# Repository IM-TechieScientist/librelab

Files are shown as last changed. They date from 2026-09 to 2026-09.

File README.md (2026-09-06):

# LibreLab

LibreLab is a low-cost, open lab instrument for embedded developers: part logic analyser, part mixed-signal scope, part signal generator, part protocol workbench. The goal is simple: make the kind of debug workflow people buy premium USB instruments for available as open hardware and open software at student/hacker-lab pricing.

Current hardware is targeting a PCB+BOM cost below `₹2500`, roughly `$26.4` at recent INR/USD rates. The next hardware revision is targeting a sub-`$50` build with RP2350B, an AD9629-class high-speed ADC path, HSTX-based high-speed data movement toward a USB 3-class host link, and generous PSRAM buffering.

## Hardware Preview

<table>
  <tr>
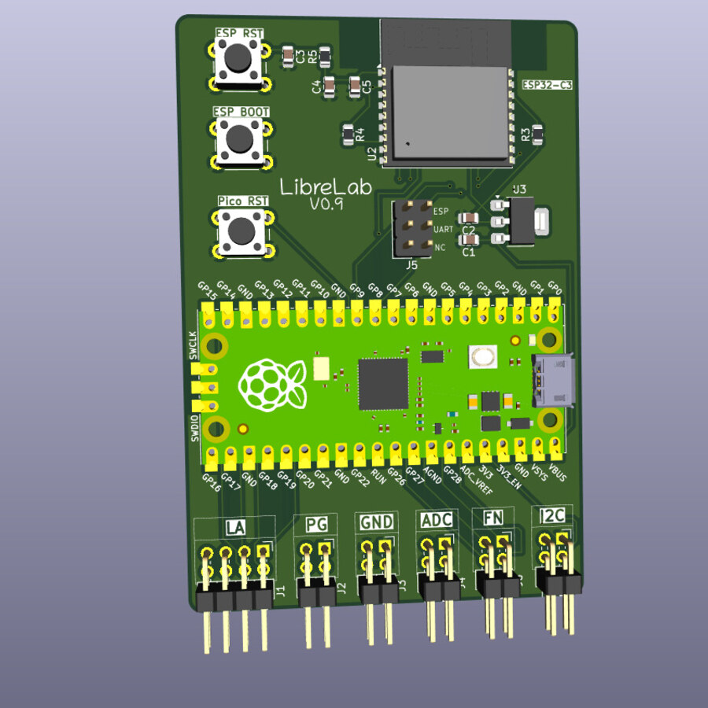
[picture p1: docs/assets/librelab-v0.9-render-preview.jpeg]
LibreLab v0.9 assembled board render
    <td width="33%"></td>
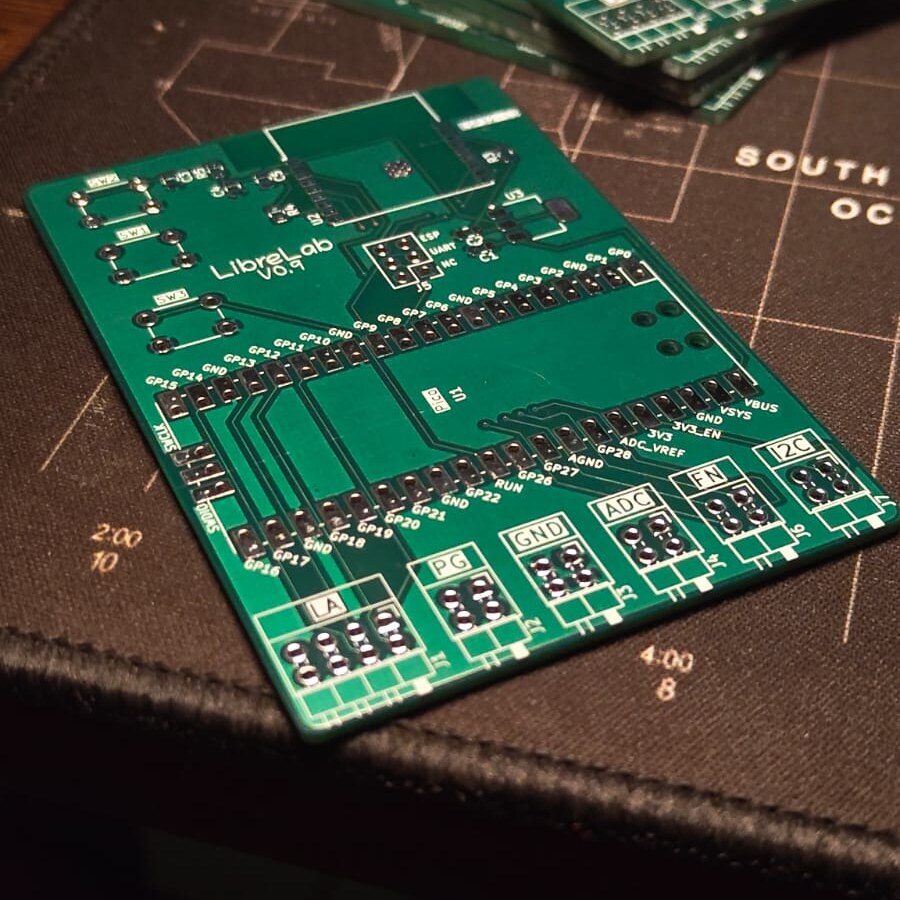
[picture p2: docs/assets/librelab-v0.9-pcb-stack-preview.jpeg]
LibreLab v0.9 PCB panel photo
    <td width="33%"></td>
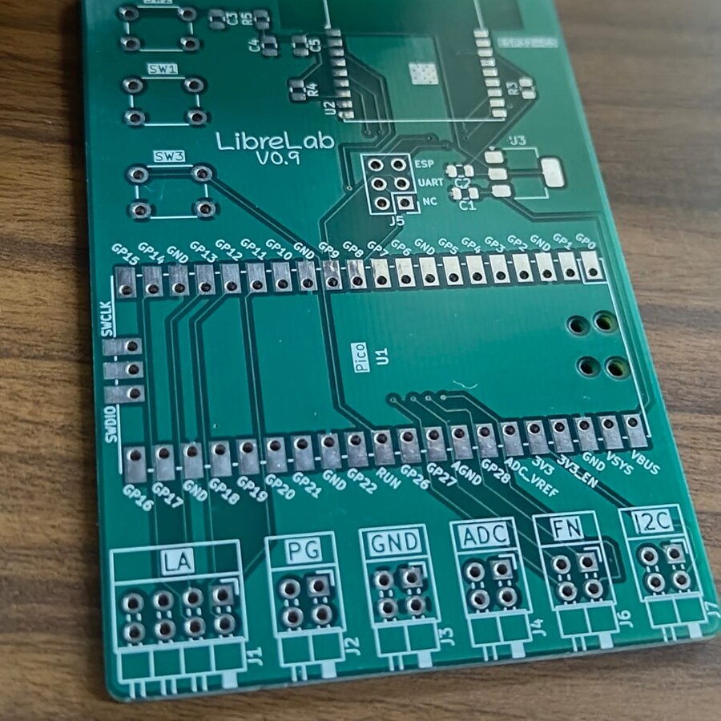
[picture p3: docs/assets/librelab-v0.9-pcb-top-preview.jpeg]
LibreLab v0.9 PCB top photo
    <td width="33%"></td>
  </tr>
  <tr>
    <td align="center">v0.9 board render</td>
    <td align="center">fabricated PCB stack</td>
    <td align="center">PCB top side</td>
  </tr>
</table>

## Software Preview

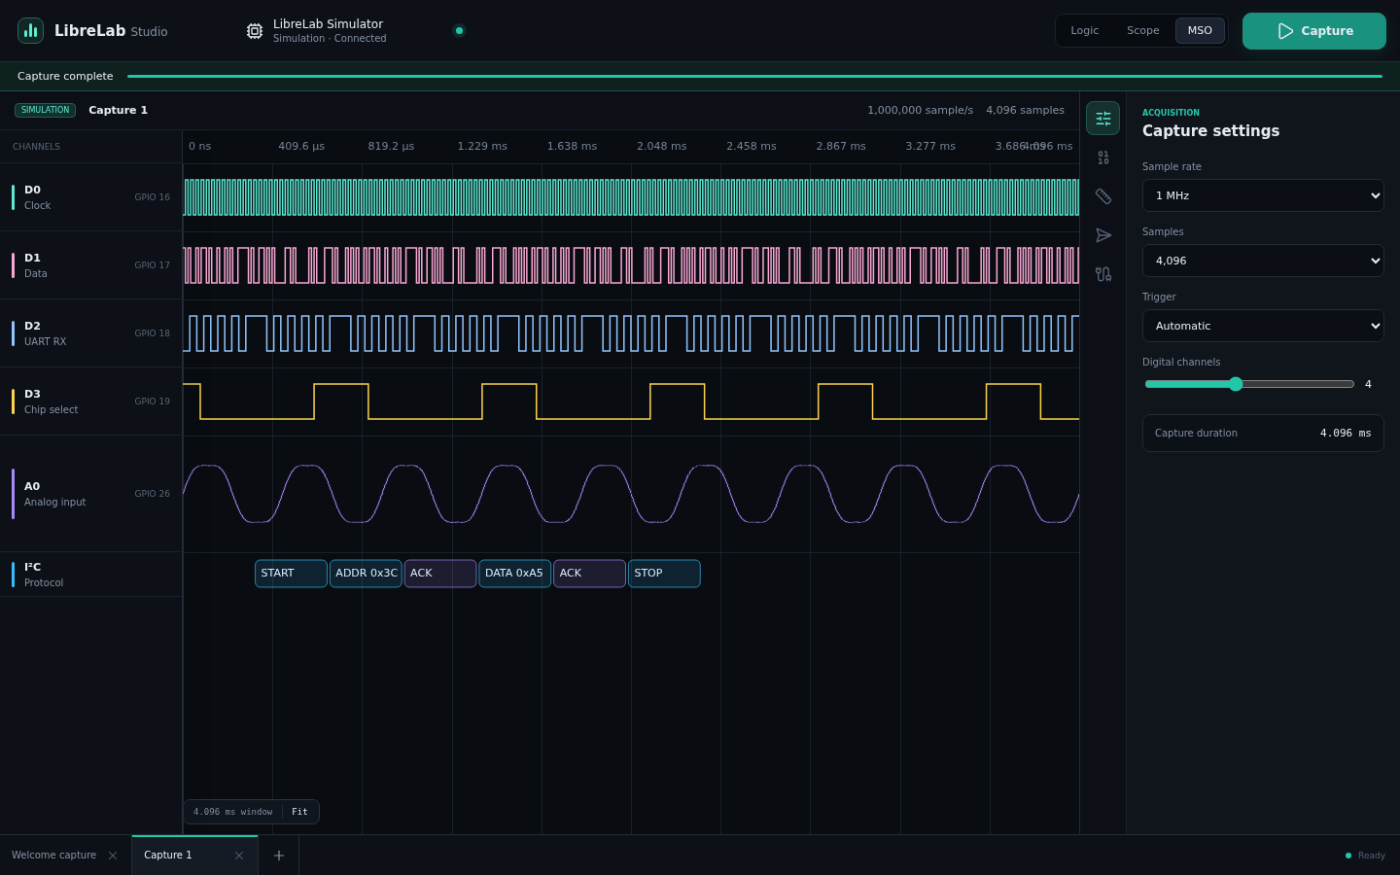
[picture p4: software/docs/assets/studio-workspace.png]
LibreLab Studio capture workspace


## Why This Is Interesting

Saleae's current Logic 8 is an 8-channel USB analyser rated at up to 100 MS/s digital capture, 10 MS/s analog capture, 10-bit analog resolution, long PC-streamed captures, 25+ protocol decoders, trigger/search, measurements, automation, and cross-platform software.

LibreLab is aiming at that workflow from the other side of the cost curve:

- `150 MSPS` logic capture on the current RP2350 design path.
- `200 MSPS` logic capture under active development.
- `400 MSPS` burst-mode capture under active development.
- Logic analyser, oscilloscope, mixed-signal capture, pattern generation, test outputs, and bus gateways in one firmware stack.
- USB CDC SCPI today, with optional ESP32-C3 Wi-Fi bridge transport.
- First-party modern desktop software plus PulseView/libsigrok integration for people who prefer the classic sigrok workflow.
- Roadmap hardware aimed at high-speed analog capture and deeper buffering while staying below `$50`.

The bet is that a carefully designed RP2350-class instrument can be brutally useful for firmware bring-up, protocol debugging, education, and small-lab automation without needing a $500-class box on every desk.

## Current Firmware

The firmware lives in [firmware](firmware/) and currently targets Pico 2/RP2350A. Firmware was originally developed by me as part of GSoC 2026.

Implemented so far:

- SCPI 1999-style command interface over USB CDC.
- 1-8 channel PIO/DMA logic analyser.
- One-channel RP2350 internal-ADC oscilloscope path.
- Synchronized mixed-signal one-shot capture.
- 1-8 channel digital pattern generator.
- UART and I2C bus gateways.
- SPI gateway code path, with a known bus-number mismatch still to fix.
- Square-wave and PWM-based analog test outputs.
- ESP32-C3 bridge firmware for TCP SCPI, UDP capture frames, SoftAP provisioning, and mDNS.
- Out-of-tree libsigrok/PulseView driver source.

Useful docs:

- [Firmware README](firmware/README.md)
- [Firmware architecture](firmware/docs/architecture.md)
- [SCPI command reference](firmware/docs/scpi-reference.md)
- [Hardware resources](firmware/docs/hardware.md)
- [RP2350B migration plan](firmware/docs/rp2350b-migration.md)

## Current Software

The desktop application lives in [software](software/) and is built with Electron, React, and TypeScript.

Implemented so far:

- Saleae-style capture workspace with channel rail, session tabs, timeline canvas, and right-side inspector.
- Logic, scope, and mixed-signal modes.
- Deterministic simulator device, so the GUI can be tested without hardware.
- Digital and analog waveform rendering with zoom, pan, fit, hover cursor, and A/B markers.
- Analyzer, measurement, output, and bus-console panels.
- Simulated I2C annotation lane using the same annotation model planned for libsigrokdecode.
- Unit, component, build, and GUI smoke tests.

More:

- [Software README](software/README.md)
- [Software architecture](software/docs/architecture.md)
- [Software feature map](software/docs/features.md)
- [Software testing](software/docs/testing.md)

Run it:

```bash
cd software
npm install
npm run dev
```

Run the browser-rendered GUI for quick UI work:

```bash
cd software
npm run dev:renderer -- --host 127.0.0.1
```

## Hardware Snapshot

The KiCad project lives in [pcb/librelab](pcb/librelab/). The current schematic/PCB includes:

- Raspberry Pi Pico module footprint.
- ESP32-C3-WROOM-02 wireless bridge module.
- AMS1117-3.3 regulator.
- Logic analyser headers.
- Pattern-generator headers.
- ADC headers.
- I2C headers.
- Function/test-output headers.
- Ground headers and reset/boot buttons.
- Generated fabrication outputs under `pcb/librelab/output/`.

## Roadmap

Near-term:

- Connect LibreLab Studio to the real USB SCPI firmware.
- Add capture import/export formats.
- Wire libsigrokdecode into a worker so GUI protocol annotations come from real decoders.
- Finish the SPI gateway bus-number fix.
- Keep PulseView support working alongside the first-party app.

Hardware vNext:

- RP2350B for a cleaner, conflict-free pin map.
- AD9629-class external ADC frontend for serious analog capture.
- HSTX-based high-speed data path toward USB 3-class streaming.
- PSRAM-backed captures and burst buffering.
- 200 MSPS sustained logic capture target and 400 MSPS burst experiments.
- Sub-`$50` target cost.

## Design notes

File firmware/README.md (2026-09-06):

# LibreLab Pico firmware

Firmware for the RP2350-based LibreLab Pico instrument, plus companion firmware
for an ESP32-C3 Wi-Fi bridge. The current build targets Pico 2/RP2350A; a future
LibreLab PCB is planned around the 48-GPIO RP2350B. The RP2350 exposes a SCPI
interface over USB CDC and implements digital capture, analog capture,
mixed-signal acquisition, pattern generation, peripheral-bus gateways, test
outputs, and optional wireless transport.

Features and limits below describe the current build.

## What is included

| Area | Capability | Current state |
| --- | --- | --- |
| Control | SCPI 1999 command parser over USB CDC | Built and usable |
| Logic analyser | 1–8 consecutive GPIO channels, PIO/DMA capture, triggers, finite capture, streaming | Built and usable |
| Oscilloscope | One RP2350 ADC channel, DMA capture, level/edge trigger, finite capture, streaming | Built and usable |
| Mixed-signal | Synchronized digital and analog one-shot capture | Built and usable |
| Pattern generator | 1–8 consecutive GPIO outputs, packed patterns, one-shot/loop modes | Built and usable |
| Bus gateway | UART1 and I2C0/I2C1 access through SCPI | Built; observe pin conflicts |
| Bus gateway | SPI1 access through SCPI | Compiled, but blocked by a known logical bus-number mismatch |
| Test outputs | Digital square wave and PWM-based “analog” waveform | Built and usable |
| Wireless | ESP32-C3 SPI bridge, TCP SCPI, UDP captures, SoftAP provisioning, mDNS | Built and usable with two-board wiring |
| ADC abstraction | ADC frontend registry with RP2350 internal ADC backend | Built and used by DSO/MSO |
| Host integration | Out-of-tree libsigrok/PulseView driver | Source included; integration into libsigrok is manual |

## Quick start

### Requirements

- Raspberry Pi Pico SDK 2.1 or newer
- CMake 3.13 or newer
- Ninja or Make
- Arm GNU toolchain (`arm-none-eabi-gcc`)
- A Pico 2/RP2350A board for the current target

Set `PICO_SDK_PATH` to the SDK checkout, then configure and build:

```bash
export PICO_SDK_PATH=/path/to/pico-sdk
cmake -S . -B build-pico2 -DPICO_BOARD=pico2
cmake --build build-pico2 --target librelab_pico -j
```

The useful outputs are normally:

```text
build-pico2/librelab_pico.elf
build-pico2/librelab_pico.bin
build-pico2/librelab_pico.hex
build-pico2/librelab_pico.uf2
```

Hold BOOTSEL while connecting the Pico, then copy the UF2 file to the mounted
`RPI-RP2` volume. Alternatively, use a debug probe or `picotool`.

After reboot, find the CDC port and query the device:

```bash
python3 -m serial.tools.miniterm /dev/ttyACM0 115200 --raw
```

Then send:

```text
*IDN?
```

Expected identification:

```text
FOSSASIA,LibreLab Pico,1.0,v0.1.0
```

The baud value is conventional for terminal software; USB CDC does not use it
to clock the physical USB connection.

## Feature examples

SCPI keywords are case-insensitive. Uppercase letters in the reference indicate
the required short form; lowercase letters are optional. Terminate commands
with `\n` or `\r\n`.

Logic analyser one-shot capture:

```text
LA:CONF:PINB 16
LA:CONF:PINC 2
LA:CONF:SAMP 1024
LA:CONF:TRIG:MODE AUTO
LA:READ?
```

Oscilloscope capture on ADC0/GPIO26:

```text
DSO:CONF:CHAN 0
DSO:CONF:RATE 100000
DSO:CONF:SAMP 1024
DSO:CONF:TRIG:MODE OFF
DSO:READ?
```

I2C two-byte read:

```text
BUS:I2C:CONF:BUS 1
BUS:I2C:CONF:ADDR 60
BUS:I2C:OPEN
BUS:I2C:READ? 2
```

Binary arguments and responses use SCPI definite-length arbitrary blocks. See
[SCPI command reference](docs/scpi-reference.md) and
[binary data formats](docs/data-formats.md) before writing a host client.

## Hardware resources at a glance

This is the current Pico 2/RP2350A mapping, not the planned RP2350B mapping.

| Function | Default RP2350 resources |
| --- | --- |
| Logging | UART0 TX GPIO0, RX GPIO1, 115200 8N1 |
| Wi-Fi bridge | SPI0 GPIO2–5, READY GPIO6 |
| UART gateway | UART1 TX GPIO4, RX GPIO5 |
| I2C gateway | I2C0 GPIO0/1 or I2C1 GPIO6/7 |
| SPI gateway | SPI1 SCK GPIO10, MOSI GPIO11, MISO GPIO12, CS GPIO13 |
| Square test output | GPIO15, 1 kHz, 50% duty |
| PWM “analog” test output | GPIO13, 1 kHz, 50% duty |
| Logic analyser | GPIO16 onward; 2 channels by default |
| Pattern generator | GPIO16 onward; 1 channel by default |
| Mixed-signal digital | GPIO16 onward; 1 channel by default |
| Internal ADC | ADC0–ADC3 on GPIO26–GPIO29 |

These defaults overlap. In particular, UART1 overlaps the Wi-Fi bridge, I2C0
overlaps the logging UART, I2C1 overlaps the Wi-Fi READY pin, GPIO13 is shared by
the default SPI chip-select and PWM test output, and the default LA/MSO/pattern
generator all begin at GPIO16. There is no central pin-ownership manager yet.
Read [hardware resources](docs/hardware.md) before enabling features together.

RP2350B provides 48 rather than 30 GPIOs, so a new PCB can assign all of these
functions to different pads. That makes the present pad conflicts avoidable,
but it is not a drop-in firmware change: RP2350B analog inputs are GPIO40–47,
PIO access to GPIO32–47 uses the GPIO16–47 window, and this source currently
contains A-specific pin limits and mappings. See the verified
[RP2350B PCB and firmware migration plan](docs/rp2350b-migration.md).

## Documentation

- [Documentation index](docs/README.md)
- [Getting started](docs/getting-started.md)
- [Building and flashing](docs/building.md)
- [Hardware resources and wiring](docs/hardware.md)
- [RP2350B PCB and firmware migration](docs/rp2350b-migration.md)
- [Firmware architecture](docs/architecture.md)
- [Complete SCPI command reference](docs/scpi-reference.md)
- [Binary and transport data formats](docs/data-formats.md)
- [Testing](docs/testing.md)
- [Development guide](docs/development.md)
- [Troubleshooting](docs/troubleshooting.md)

Feature guides:

- [Logic analyser](docs/features/logic-analyser.md)
- [Oscilloscope](docs/features/oscilloscope.md)
- [Mixed-signal capture](docs/features/mixed-signal.md)
- [Digital pattern generator](docs/features/pattern-generator.md)
- [UART, I2C, and SPI gateways](docs/features/bus-gateways.md)
- [Test-signal outputs](docs/features/test-signals.md)
- [Wi-Fi bridge](docs/features/wifi-bridge.md)
- [Internal ADC frontend](docs/features/adc-frontends.md)

## Repository layout

```text
src/application/        SCPI parser integration and feature command adapters
src/system/             Hardware-independent instruments, buses, transport, logging setup
src/platform/           RP2350/Pico SDK drivers
src/util/               Circular buffer, error, and logging utilities
esp_firmware/           ESP-IDF project for the ESP32-C3 bridge
tools/sigrok/           Out-of-tree libsigrok driver
lib/                    Vendored firmware dependencies
docs/                   User, protocol, architecture, and developer documentation
```

The runtime starts in `src/application/main.c`, initializes system services,
initializes the SCPI protocol, then repeatedly services USB, Wi-Fi command
polling, instrument streams, the pattern generator, and buffered logs.

## Known limitations

- The SPI SCPI gateway uses external bus number `1`, while its system layer
  currently exposes one logical bus numbered `0`; `BUS:SPI:OPEN` therefore
  fails until those conventions are aligned.
- Non-automatic finite LA triggers and triggered finite DSO captures can wait
  indefinitely if the trigger never arrives. MSO uses a one-second timeout;
  streaming DSO uses a 10 ms trigger timeout per frame.
- LA and DSO streaming are mutually exclusive. MSO has no streaming mode.
- The 1024-byte SCPI input buffer limits the effective size of a single
  `PG:DATA` upload even though the pattern buffer itself is 64 KiB.
- Wi-Fi command polling is disabled in the default USB transport mode. Select
  `COMM:TRAN WIFI` or `COMM:TRAN AUTO` over USB before controlling a newly
  booted Pico only through Wi-Fi.

## License

LibreLab firmware sources are licensed under Apache-2.0. Vendored components
retain their own licenses; see [LICENSE.md](LICENSE.md) and the license files in
`lib/`.

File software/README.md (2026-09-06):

# LibreLab Studio

LibreLab Studio is the desktop control and analysis application for LibreLab instruments. The current implementation is an Electron, React, and TypeScript app with a Saleae-style capture workspace, a deterministic simulator, and automated tests that run without hardware.

This is the first vertical slice. It is designed so the UI, capture contract, renderer tests, and GUI smoke tests are usable now while the native hardware engine and libsigrokdecode bridge are added behind the same API.

## What Works Today

- Logic, oscilloscope, and mixed-signal workspace modes.
- Built-in LibreLab simulator exposed through the same API shape planned for hardware devices.
- Capture settings for sample rate, sample count, trigger mode, and digital channel count.
- Timeline viewport with digital traces, analog traces, zoom, pan, fit, hover cursor, and A/B marker measurement.
- I2C-style protocol annotations in the simulator.
- Analyzer, measurement, output, and bus-console side panels.
- Browser-side fallback simulator for component tests.
- GUI smoke test that captures data without hardware.

## Screenshots

LibreLab Studio capture workspace

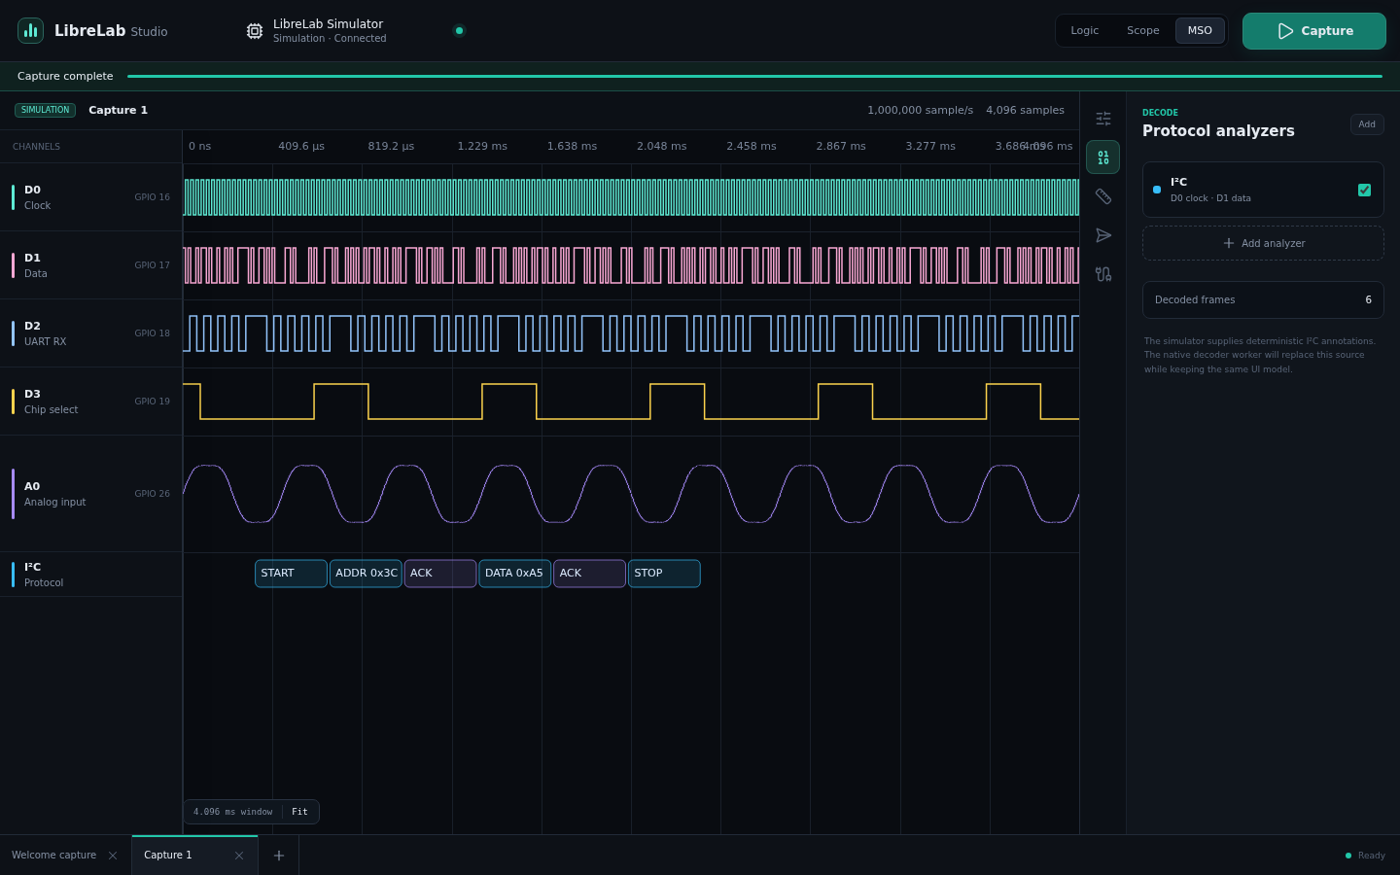
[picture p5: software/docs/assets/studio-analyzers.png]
LibreLab Studio analyzer panel


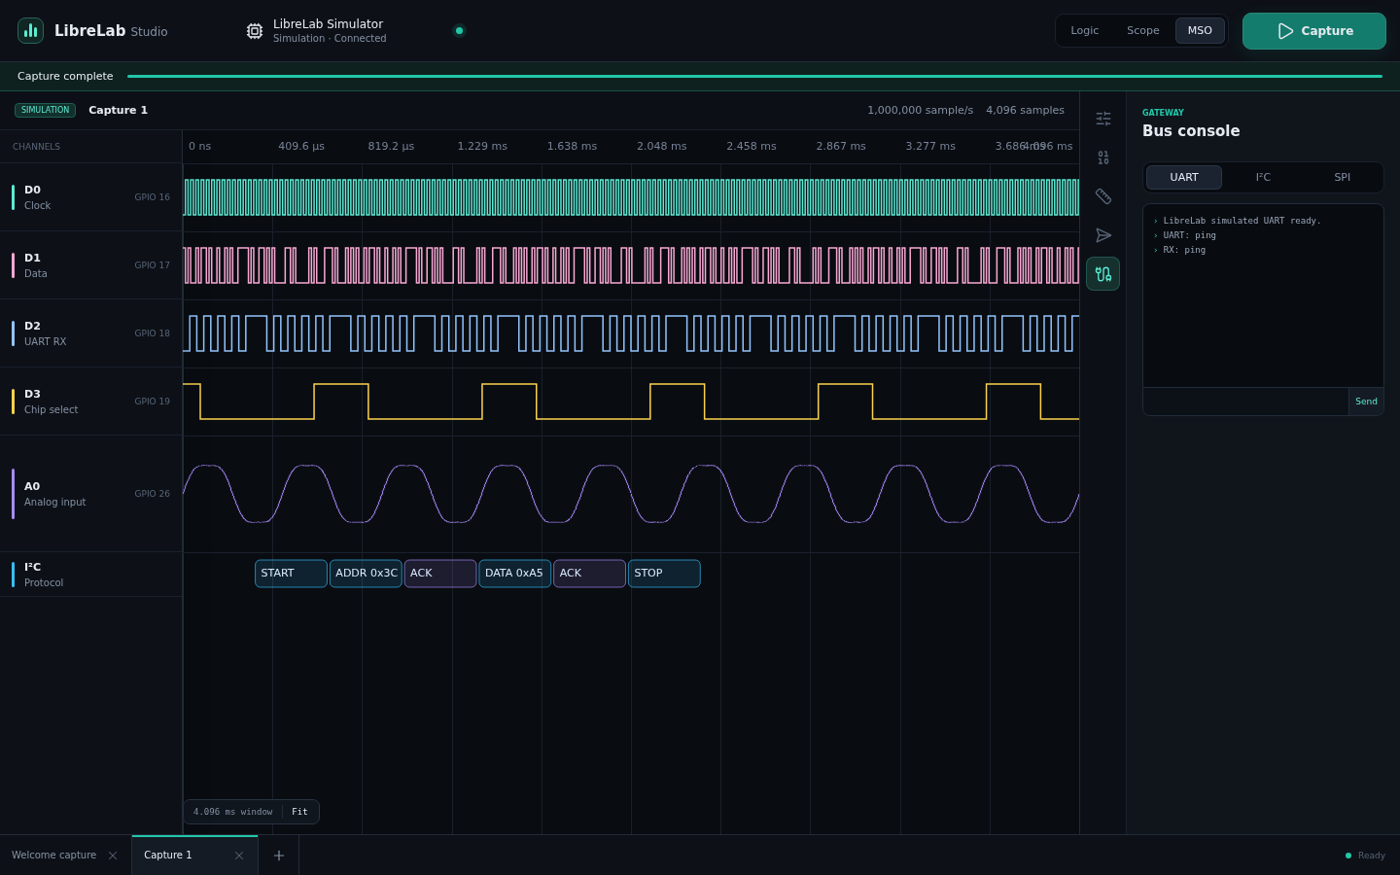
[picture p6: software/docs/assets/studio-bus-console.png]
LibreLab Studio bus console


## Commands

Run from this directory:

```bash
npm install
npm run dev
npm run typecheck
npm test
npm run test:e2e
npm run test:all
npm run docs:screenshots
npm run build
npm run package
```

`npm run dev` starts the Electron development app.

`npm run dev:renderer` starts only the renderer in a browser. This is useful for fast UI work and is the mode used by Playwright smoke tests.

`npm test` runs unit and component tests in jsdom.

`npm run test:e2e` builds the desktop app and runs the Playwright GUI smoke test against the renderer simulator in Chromium. On a fresh machine, install the Playwright browser once:

```bash
npx playwright install chromium
```

`npm run docs:screenshots` refreshes the screenshots in `docs/assets/`.

## Project Layout

```text
software/
  src/main/              Electron main process and device-service IPC
  src/preload/           Secure context bridge exposed as window.librelab
  src/renderer/src/      React app, waveform canvas, panels, styles
  src/shared/            Capture/device contracts and deterministic simulator
  tests/e2e/             Playwright GUI smoke tests
  docs/                  Architecture and testing notes
```

## Development Notes

The renderer never talks directly to Node, USB, or native libraries. It calls `window.librelab`, which is provided by the preload script in Electron and by a browser simulator in tests. That keeps the app secure and makes every GUI workflow testable without plugging in a board.

The future hardware path should implement the existing shared contracts first, then replace the mock device service with a native device engine. Protocol decoding should follow the same pattern: the UI consumes annotation records; a native worker can later fill those records from libsigrokdecode.

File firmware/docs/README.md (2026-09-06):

# LibreLab firmware documentation

This directory is the authoritative documentation for the integrated RP2350
firmware and ESP32-C3 bridge. Unless a section is explicitly marked as a future
RP2350B design, values and limitations describe the current Pico 2/RP2350A
source tree.

## Start here

1. [Getting started](getting-started.md) — build, flash, connect, and run a first capture.
2. [Hardware resources](hardware.md) — pin mapping, wiring, voltage rules, and conflicts.
3. [RP2350B migration](rp2350b-migration.md) — verified package differences,
   conflict-free routing example, and required firmware work.
4. [SCPI command reference](scpi-reference.md) — every command registered by the firmware.
5. [Binary data formats](data-formats.md) — arbitrary blocks, packed samples, USB streams, and Wi-Fi frames.

## Build and maintenance

- [Building and flashing](building.md) — RP2350 and ESP32-C3 toolchains and artifacts.
- [Testing](testing.md) — build verification, sigrok tests, and current test-suite status.
- [Development guide](development.md) — source ownership, adding features, style, and review checklist.
- [Troubleshooting](troubleshooting.md) — common build, USB, capture, bus, and wireless failures.

## Architecture

- [Firmware architecture](architecture.md) — layer boundaries, boot flow,
  runtime scheduling, errors, and resource ownership.
- [RP2350B migration](rp2350b-migration.md) — future PCB pin planning and
  package-aware architecture changes.
- [Binary data formats](data-formats.md) — application and bridge protocol layouts.
- [Wi-Fi bridge](features/wifi-bridge.md) — two-MCU architecture, provisioning, TCP, UDP, SPI, and mDNS.

## Feature guides

| Feature | Guide |
| --- | --- |
| PIO/DMA logic analyser | [Logic analyser](features/logic-analyser.md) |
| Internal-ADC oscilloscope | [Oscilloscope](features/oscilloscope.md) |
| Synchronized analog + digital capture | [Mixed-signal capture](features/mixed-signal.md) |
| PIO/DMA digital output | [Pattern generator](features/pattern-generator.md) |
| UART, I2C, and SPI host gateways | [Bus gateways](features/bus-gateways.md) |
| Digital and PWM test outputs | [Test signals](features/test-signals.md) |
| USB/TCP/UDP wireless transport | [Wi-Fi bridge](features/wifi-bridge.md) |
| Internal ADC abstraction | [ADC frontend](features/adc-frontends.md) |

## Documentation conventions

- GPIO numbers are RP2350 GPIO numbers, not physical header pin numbers.
- Rates are in hertz unless explicitly labelled otherwise.
- Timeouts exposed by SCPI are in milliseconds; lower layers commonly store
  them in microseconds.
- `uint16_t` and `uint32_t` payloads are little-endian.
- In SCPI command spellings, uppercase characters form the legal short form and
  lowercase characters are optional.
- “Built” means the file is listed in the root `CMakeLists.txt`; it does not
  imply that every combination of features is electrically conflict-free.

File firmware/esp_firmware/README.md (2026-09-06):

# LibreLab ESP32-C3 bridge firmware

This ESP-IDF project is the optional network companion for LibreLab Pico. It is
an SPI slave to the RP2350 and provides SoftAP provisioning, station-mode Wi-Fi,
TCP SCPI on port 5006, UDP captures on port 5005, UDP receiver registration,
and mDNS as `librelab-pico.local` / `_librelab._tcp`.

Build and flash from an ESP-IDF 5.1.x shell:

```bash
idf.py set-target esp32c3
idf.py menuconfig
idf.py build
idf.py -p /dev/ttyUSB0 flash monitor
```

Default ESP pins are GPIO4 SCLK, GPIO5 MOSI, GPIO6 MISO, GPIO7 CS, and GPIO10
READY. Default provisioning uses AP `LibreLab-Pico-XXXX`, password
`librelab-pico`, and setup page `http://192.168.4.1`.

Read the complete [Wi-Fi bridge guide](../docs/features/wifi-bridge.md),
[wire protocol](../docs/data-formats.md), and
[troubleshooting guide](../docs/troubleshooting.md). `bridge_receiver.py` is a
synthetic-pattern link diagnostic, not a decoder for current capture payloads.

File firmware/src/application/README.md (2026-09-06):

# Application layer

This directory owns the RP2350 firmware's SCPI-facing application layer:

- `main.c` initializes the system and protocol, then runs the cooperative loop.
- `protocol/common.c` owns the parser context, complete command table, USB/Wi-Fi
  response routing, stream dispatch, and SCPI reset callback.
- `protocol/{la,dso,mso,pg}.c` and `protocol/bus/` parse parameters and format
  results.
- `*_commands.c` files retain feature configuration and adapt commands to the
  system layer.
- `gateway/` adapts the UART, I2C, and SPI SCPI gateways.

The SCPI input buffer is 1,024 bytes and the error queue contains 16 entries.
The current identification response is:

```text
FOSSASIA,LibreLab Pico,1.0,v0.1.0
```

See the authoritative [architecture](../../docs/architecture.md), complete
[SCPI reference](../../docs/scpi-reference.md), and
[development guide](../../docs/development.md).

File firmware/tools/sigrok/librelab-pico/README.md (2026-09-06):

# LibreLab Pico libsigrok Driver

This directory is an out-of-tree `libsigrok` hardware driver for the LibreLab
Mini/Pico firmware. It talks to the firmware over USB CDC using the existing
SCPI commands and feeds unpacked `SR_DF_LOGIC` samples to PulseView.

## Firmware Requirements

Flash firmware that includes:

- `LA:CONFigure:TRIGger:MODE AUTO`
- `LA:CONFigure:RATE?`
- `LA:METadata?`
- `LA:READ?` returning a SCPI arbitrary block of little-endian packed
  `uint32_t` PIO/DMA words

`AUTO` trigger mode is important because PulseView captures usually start
without a hardware trigger.

## Build Into libsigrok

1. Copy this directory to `libsigrok/src/hardware/librelab-pico`.
2. Add the directory to libsigrok's hardware-driver build files.
3. Add `librelab_pico_driver_info` to the libsigrok hardware driver registry if
   your libsigrok checkout requires explicit registration.
4. Build and install libsigrok, then build PulseView against that libsigrok.

The driver is intentionally small and POSIX-serial based. Linux is the first
target; Windows/macOS can follow by replacing the serial transport in
`protocol.c` with libsigrok's serial helpers.

## Usage

```sh
sigrok-cli --driver librelab-pico:conn=/dev/ttyACM0 --samples 1024
```

PulseView should then show `librelab-pico` as a sigrok hardware driver. Select the
CDC device path as the connection, choose enabled channels, set sample count and
sample rate, capture, and use the normal PulseView protocol decoders.

## Capture Format

Firmware returns packed PIO/DMA words. The host unpacker uses:

```text
bits_per_word = 32 - (32 % pin_count)
```

Each sample consumes `pin_count` bits. The output byte maps bit 0 to `D0`, bit
1 to `D1`, and so on.

## Local Test

The unpacker can be tested without libsigrok:

```sh
make test
```

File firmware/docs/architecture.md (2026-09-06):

# Firmware architecture

## System overview

LibreLab is split across one required MCU and one optional bridge MCU:

```text
                         USB CDC
Host <------------------------------------------------> RP2350
  ^                                                       |
  | TCP SCPI + UDP captures                               | SPI0 + READY
  +------------------------ ESP32-C3 <--------------------+
```

The RP2350 owns instrument state, capture/generation hardware, SCPI parsing, and
binary formatting. The ESP32-C3 is a transport bridge; it does not interpret
instrument commands or samples.

The current platform implementation is specialized for Pico 2/RP2350A. The
future RP2350B PCB needs a package-aware board configuration and pin map; see
[RP2350B migration](rp2350b-migration.md).

## RP2350 layers

```text
Application
  SCPI command tree, parser callbacks, feature adapters
        |
System
  Instruments, bus handles, transport policy, initialization, logging/syscalls
        |
Platform
  Pico SDK, PIO, DMA, ADC, UART, I2C, SPI, PWM, TinyUSB, GPIO
        |
RP2350 hardware
```

### Application layer

`src/application/protocol/common.c` owns the SCPI context, command table, input
buffers, output routing, and stream dispatch. Feature protocol files parse SCPI
parameters and translate failures into SCPI errors. Command-adapter files retain
application state where appropriate and call the system layer.

### System layer

The system layer defines hardware-independent handles and instrument behavior:

- `system/logic_analyser.*` — packed digital capture model.
- `system/instrument/dso.*` — one-channel analog acquisition and triggering.
- `system/instrument/mixed_signal.*` — coordinated PIO + ADC capture.
- `system/pattern_generator.*` — output lifecycle and modes.
- `system/instrument/adc_frontend.*` — selectable ADC backend registry.
- `system/bus/*` — handle ownership for UART/I2C/SPI.
- `system/transport.*` — USB/Wi-Fi policy and wireless capture framing.
- `system/system.*` — startup, reset, logging UART, and exception handling.

### Platform layer

Only platform modules should call Pico SDK hardware APIs. They implement
TinyUSB CDC, PIO state machines, DMA setup, internal ADC capture, UART IRQs,
I2C/SPI controllers, the Pico-to-ESP link, PWM outputs, clocks, watchdog reset,
and the status LED.

### Utility layer

`src/util` contains the circular buffer, logging queue, SI-prefix constants,
and the CException-based error model.

## Startup sequence

```text
main
  -> SYSTEM_init
       -> LOG_init
       -> PLATFORM_init
            -> register internal ADC frontend
       -> initialize UART0 logging and newlib syscalls
       -> status LED
       -> test-signal state
       -> TinyUSB CDC
       -> transport defaults (USB)
  -> protocol_init
       -> SCPI parser/context and command table
  -> forever
       -> protocol_task
       -> drain buffered logs
```

`protocol_task()` is cooperative, not an RTOS task. It services the pattern
generator, TinyUSB, up to 64 bytes of USB input, up to 256 bytes of wireless
input, then advances LA and DSO streams.

## Command flow

```text
USB CDC bytes or ESP SPI SCPI frame
  -> SCPI_Input
  -> command callback
  -> application adapter
  -> system instrument/bus
  -> platform driver
  -> response callback
  -> originating USB or Wi-Fi path
```

The active response destination is selected per command source. USB remains the
default after a wireless command finishes.

## Capture flow

### Logic analyser

PIO0 SM0 samples consecutive GPIO bits. RX FIFO requests drive a DMA channel
into a packed `uint32_t` buffer. The application supports finite capture and a
double-buffered stream.

### Oscilloscope

The ADC frontend selects the internal backend. ADC FIFO requests drive DMA into
a `uint16_t` buffer. Trigger detection is performed with single ADC reads before
the DMA acquisition begins.

### Mixed-signal

The ADC and logical analyser are configured and armed first. The logic trigger
is awaited, then ADC and PIO capture are started in sequence. Reported start
offsets are currently zero placeholders rather than measured skew.

### Pattern generation

PIO0 SM1 shifts packed samples to consecutive GPIO pins. A data DMA channel
feeds the TX FIFO; loop mode uses a control DMA channel to restart the transfer.

## Transport architecture

USB responses and finite captures use normal SCPI text or arbitrary blocks.
USB streams add a textual frame header before each arbitrary block. Wireless
captures are wrapped in an inner LibreLab capture frame, then a fixed 512-byte
Pico/ESP bridge frame. See [binary data formats](data-formats.md).

Transport policy is:

- `USB`: no Pico polling of the ESP command path; capture streams use USB.
- `WIFI`: initialize/use the ESP path and route capture streams through it.
- `AUTO`: use Wi-Fi when READY is asserted, otherwise USB.

## Errors and logging

SCPI errors and firmware logs are separate:

- Parse/command failures enter a 16-entry SCPI error queue read with
  `SYST:ERR?`.
- Internal logs enter a circular buffer and are drained to stdout/stderr.
- Newlib stdout/stderr is routed through UART0 at 115200 baud.
- An uncaught CException logs a fatal message, flushes logs with a bounded
  timeout, and resets through the watchdog.

## State and reset behavior

`*RST` resets LA, DSO, MSO, and pattern-generator state. It does not erase ESP
NVS, alter build-time pin mapping, or reboot either MCU. Bus gateway handles are
not explicitly reset by the SCPI reset callback in the current implementation.

## Concurrency and ownership constraints

- The RP2350 main loop is cooperative; long blocking captures delay other SCPI
  and log processing.
- Finite triggered LA/DSO operations may wait indefinitely.
- LA and DSO streams explicitly stop one another.
- MSO shares both LA and ADC resources but does not coordinate with an already
  active stream; clients should stop streams first.
- GPIO ownership is implicit. See [hardware resources](hardware.md).
- DMA channels are claimed dynamically, so initialization can fail when the
  pool is exhausted.

## Package boundary

RP2350A and RP2350B share the firmware layers and peripheral-controller model,
but the package is an explicit platform concern. Board-specific code must own:

- valid GPIO count and fixed peripheral pin routes;
- ADC channel count and channel-to-GPIO mapping;
- the PIO GPIO window shared by state machines on each PIO instance;
- LED, flash, ESP-link, gateway, and test-output assignments.

Those values are currently distributed as constants in platform, system, and
application modules. Consolidating them into a board profile is a prerequisite
for maintaining both A and B targets without silently applying A mappings to B.

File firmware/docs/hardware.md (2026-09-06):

# Hardware resources and wiring

The current firmware target is a Raspberry Pi Pico 2, which uses the 30-GPIO
RP2350A package, and optionally an ESP32-C3. A future LibreLab PCB is planned
around RP2350B. GPIO numbers below are chip GPIO numbers. Consult the board
pinout or schematic for physical positions.

RP2350B has enough additional pads to remove the conflicts in the current map,
provided the PCB and firmware assign each function a distinct compatible pad.
It does not automatically resolve conflicts in the current binary. See the
[RP2350B migration plan](rp2350b-migration.md) for the verified differences and
a candidate conflict-free allocation.

## Electrical rules

- RP2350 GPIO is 3.3 V logic and is not 5 V tolerant.
- Connect grounds between LibreLab, an ESP bridge, probes, and target circuits.
- Keep analog input voltage within the board/ADC limits.
- External I2C pull-ups must go to 3.3 V. The current default configuration also
  enables the RP2350 internal pull-ups.
- Do not drive a pin from the pattern/test generators while an external device
  also drives it.

## Current RP2350A default pin map

| GPIO | Default owner/use | Direction | Notes |
| --- | --- | --- | --- |
| 0 | UART0 TX / I2C0 SDA | Output / bidirectional | Logging and I2C0 conflict |
| 1 | UART0 RX / I2C0 SCL | Input / bidirectional | Logging and I2C0 conflict |
| 2 | ESP bridge SPI0 SCK | Output | Allocated when Wi-Fi/AUTO transport initializes |
| 3 | ESP bridge SPI0 MOSI | Output | Pico to ESP |
| 4 | ESP SPI0 MISO / UART1 TX | Input / output | Wi-Fi and UART gateway conflict |
| 5 | ESP SPI0 CS / UART1 RX | Output / input | Wi-Fi and UART gateway conflict |
| 6 | ESP READY / I2C1 SDA | Input / bidirectional | Wi-Fi and I2C1 conflict |
| 7 | I2C1 SCL | Bidirectional | Paired with GPIO6 |
| 10 | SPI1 SCK | Output | Generic SPI gateway |
| 11 | SPI1 MOSI | Output | Generic SPI gateway |
| 12 | SPI1 MISO | Input | Generic SPI gateway |
| 13 | SPI1 CS / PWM test output | Output | SPI and analog-test conflict |
| 15 | Square-wave test output | Output | 1 kHz default |
| 16–23 | LA/MSO inputs or pattern outputs | Configurable | Consecutive group, defaults begin at 16 |
| 26 | ADC0 | Analog input | Default DSO/MSO analog channel |
| 27 | ADC1 | Analog input | Internal ADC channel 1 |
| 28 | ADC2 | Analog input | Internal ADC channel 2 |
| 29 | ADC3 | Analog input | Internal ADC channel 3 |

The onboard status LED uses `PICO_DEFAULT_LED_PIN` when the selected Pico SDK
board definition supplies one.

## ESP32-C3 bridge wiring

| Pico 2 | Signal | ESP32-C3 default |
| --- | --- | --- |
| GPIO2 | SPI0 SCK | GPIO4 |
| GPIO3 | SPI0 MOSI | GPIO5 (input) |
| GPIO4 | SPI0 MISO | GPIO6 (output) |
| GPIO5 | SPI0 CS | GPIO7 |
| GPIO6 | READY | GPIO10 (output) |
| GND | Common ground | GND |

The Pico is SPI master, the ESP is SPI slave, mode 0, MSB first, at 1 MHz. The
ESP asserts READY only while it has queued a transaction.

## Peripheral assignments

| Resource | Firmware use |
| --- | --- |
| PIO0 state machine 0 | Logic analyser and MSO digital capture |
| PIO0 state machine 1 | Pattern generator |
| SPI0 | Optional Pico-to-ESP bridge |
| SPI1 | Generic SPI gateway backend |
| UART0 | Buffered log/stdout transport |
| UART1 | Generic UART gateway |
| ADC + ADC FIFO | DSO and MSO analog capture |
| PWM slices | Square and PWM-based analog test outputs |
| DMA | Claimed dynamically by LA, pattern generator, ADC, and ESP bridge |

LA and MSO share the same logical-analyser backend and cannot capture
simultaneously. DSO and MSO share the ADC backend. Resource allocation is local
to each module; there is no global arbiter.

## Current configurable and fixed mappings

- LA, MSO digital pins, trigger pins, pattern pins, and test-output pins are
  configurable with SCPI.
- DSO/MSO analog input is selected by ADC channel; mapping is fixed to GPIO26–29.
- UART gateway pins are fixed to UART1 GPIO4/5.
- I2C gateway pins are fixed per bus to GPIO0/1 or GPIO6/7.
- SPI gateway pins are fixed to GPIO10–13 by the current application gateway.
- Pico-to-ESP pins are compile-time constants on the Pico side and Kconfig
  options on the ESP side. Changing only one side breaks the link.

## Recommended combinations

- USB + LA/DSO/MSO/PG: avoid overlapping chosen capture/output pins.
- USB + UART gateway: safe with default pins; logging remains on UART0.
- USB + I2C1: usable if the ESP bridge is not connected/enabled.
- Wi-Fi + generic UART: not safe with defaults because both use GPIO4/5.
- Wi-Fi + I2C1: not safe with defaults because both use GPIO6.
- SPI gateway + PWM analog test: not safe with defaults because both use GPIO13.

If a board design requires simultaneous use of conflicting features, change
the platform mapping in code and treat the change as a board configuration,
then update this document.

## Future RP2350B board

RP2350B expands bank 0 from GPIO0–29 to GPIO0–47. This creates enough pad-level
space to separate logging, the ESP bridge, all three bus gateways, test outputs,
an eight-bit LA bank, an eight-bit pattern bank, and the ADC inputs. Peripheral
controllers are unchanged in count, so the design still has two UARTs, two
SPIs, and two I2Cs; extra pads are alternate routes, not extra controllers.

The package also changes two rules which the PCB and firmware must follow:

- ADC0–ADC7 are on GPIO40–GPIO47. GPIO26–GPIO29 are not ADC inputs on RP2350B.
- Each PIO instance can address either GPIO0–31 or GPIO16–47. PIO0 must select
  the latter window if the pattern bank uses GPIO32 or above, and all active
  state machines on that PIO must fit the same window.

Do not use the current `pico2` image on that board as a functional validation
image. It identifies an RP2350A target, limits multiple features to GPIO0–29,
and maps internal ADC channels to GPIO26–29.

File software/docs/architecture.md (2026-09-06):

# LibreLab Studio Architecture

LibreLab Studio is split into four layers:

```text
Renderer UI -> Preload API -> Main process service -> Device/decoder engine
```

## Renderer UI

The renderer is a React application under `src/renderer/src`.

- `App.tsx` owns workspace state: devices, active capture settings, capture sessions, active side panel, progress, and errors.
- `WaveformViewport.tsx` draws digital, analog, marker, and decoder tracks onto a canvas.
- `SidePanel.tsx` contains capture controls, protocol analyzers, measurements, output controls, and the bus console.
- `lib/api.ts` returns the Electron preload API when available and a browser simulator when the renderer is tested outside Electron.

The renderer only consumes typed data from `src/shared/contracts.ts`. It does not import Electron APIs, use Node APIs, or assume hardware is attached.

## Preload API

`src/preload/index.ts` exposes a narrow `window.librelab` bridge through Electron `contextBridge`.

Available methods:

- `listDevices()`
- `connect(deviceId)`
- `disconnect(deviceId)`
- `capture(deviceId, configuration)`
- `onCaptureProgress(callback)`

All future hardware and decoder work should preserve this API unless a workflow genuinely needs a new operation.

## Main Process

`src/main/index.ts` creates the desktop window and registers IPC handlers. It currently routes every call to `MockDeviceService`, which simulates discovery, connection, capture progress, and capture data.

The production hardware implementation should replace or sit beside `MockDeviceService` with a device manager that can:

- discover USB/network LibreLab devices;
- negotiate firmware capabilities;
- stream capture data;
- expose generator and bus operations;
- report recoverable connection errors;
- feed protocol decoder workers.

## Capture Model

The shared capture model is intentionally close to how waveform tools operate:

- `CaptureConfiguration` describes requested mode, sample rate, sample count, channels, and trigger.
- `CaptureSession` stores immutable captured data and annotations.
- Digital samples are `Uint8Array` values.
- Analog samples are `Float32Array` voltage values.
- Decoder output is represented as `DecoderAnnotation` spans over sample indices.

This keeps the UI independent from transport details and lets tests generate stable captures.

## Protocol Decoding

The first slice ships simulated I2C annotations. The planned decoder path is:

```text
CaptureSession samples -> decoder worker -> DecoderAnnotation[] -> waveform annotation lane
```

The worker should wrap libsigrokdecode and convert decoder output into the existing annotation model. That allows the GUI to support libsigrokdecode protocols without coupling React components to Python or native process details.

## PulseView Compatibility

PulseView support should remain a parallel export/integration path. LibreLab Studio should own the first-party experience, while firmware and capture tooling should still produce formats or sigrok driver hooks that PulseView users can consume.

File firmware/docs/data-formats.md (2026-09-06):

# Binary and transport data formats

All multi-byte integer fields defined by LibreLab are little-endian. SCPI block
lengths and USB stream headers are ASCII. No capture format currently carries
voltage calibration or timestamps per sample.

## SCPI definite-length arbitrary blocks

Binary command arguments and finite-capture responses use the SCPI form:

```text
#<number-of-length-digits><decimal-payload-length><payload>
```

For a three-byte payload, the encoded bytes begin `#13`. For 1,024 bytes they
begin `#41024`. Read the length header first and then read exactly the declared
payload length; the payload may contain any byte, including newline.

```python
def encode_block(payload: bytes) -> bytes:
    length = str(len(payload)).encode("ascii")
    return b"#" + str(len(length)).encode("ascii") + length + payload

def read_exact(port, length: int) -> bytes:
    out = bytearray()
    while len(out) < length:
        chunk = port.read(length - len(out))
        if not chunk:
            raise TimeoutError("short SCPI block")
        out.extend(chunk)
    return bytes(out)

def read_block(port) -> bytes:
    if read_exact(port, 1) != b"#":
        raise ValueError("not a definite-length block")
    digits = int(read_exact(port, 1))
    length = int(read_exact(port, digits))
    return read_exact(port, length)
```

## Logic-analyser samples

Logic-analyser and MSO digital data is an array of little-endian `uint32_t`
words. Samples are packed consecutively, least-significant group first:

```text
bits_per_word    = 32 - (32 % pin_count)
samples_per_word = bits_per_word / pin_count
word_index       = sample_index / samples_per_word
group_index      = sample_index % samples_per_word
sample_mask      = (1 << pin_count) - 1
sample           = (word[word_index] >> (group_index * pin_count)) & sample_mask
channel_n        = (sample >> n) & 1
GPIO             = pin_base + n
```

Pin count is restricted to 1–8. When it does not divide 32, the unused most
significant bits of each word are padding; for example, three channels carry ten
samples in bits 0–29. Unused groups in the last word should also be ignored using
the configured sample count. `LA:METadata?` reports the sample count, word count,
and bits per word needed to decode a finite capture.

## Pattern-generator samples

`PG:DATA` uses the same group arrangement as the logic analyser: an arbitrary
block containing little-endian `uint32_t` words, with earliest samples in the
least-significant bits. For `pin_count` outputs, each group is one simultaneous
sample and bit `n` drives `pin_base + n`. The top `32 % pin_count` bits of each
word are padding.

The application buffer holds 16,384 words (64 KiB), but the shared 1,024-byte
SCPI input buffer makes a single command substantially smaller than that. The
current protocol has no chunked upload or append command.

## Analog samples

DSO and MSO analog captures are contiguous little-endian `uint16_t` values.
Each value contains an unscaled RP2350 12-bit ADC result in bits 11:0. Bits
15:12 are not measurement data. Convert raw codes to voltage using the actual
analog reference and any external front-end gain/offset; the firmware does not
currently transmit calibration coefficients.

```python
import struct

samples = struct.unpack("<" + "H" * (len(payload) // 2), payload)
samples = tuple(value & 0x0FFF for value in samples)
```

## USB continuous-stream frames

LA and DSO streaming writes an ASCII line, a SCPI arbitrary block, and one
trailing newline:

```text
LA:STREAM:FRAME <sequence> <payload_length>\n
#<digits><length><payload>\n
```

or:

```text
DSO:STREAM:FRAME <sequence> <payload_length>\n
#<digits><length><payload>\n
```

`sequence` is an unsigned frame counter. The length in the ASCII line and the
block length should agree. Stream output is unsolicited, so stop streaming
before sending commands from a simple request/response client.

## Pico-to-ESP SPI frame

The bridge exchanges a fixed 512-byte frame over SPI. The outer header is 12
bytes and the payload area is 500 bytes.

| Offset | Size | Field |
| ---: | ---: | --- |
| 0 | 1 | Magic `0xA5` |
| 1 | 1 | Frame type: `0x00` poll, `0x02` capture data, `0x03` SCPI |
| 2 | 4 | Transport sequence, little-endian `uint32_t` |
| 6 | 2 | Valid outer payload length, little-endian `uint16_t`, maximum 500 |
| 8 | 1 | Sum of bytes 0–7 modulo 256 |
| 9 | 3 | Reserved, currently zero |
| 12 | 500 | Payload followed by zero padding |

SPI is mode 0 at 1 MHz. READY tells the Pico when the ESP slave has queued a
transaction. The ESP validates magic, type, length, and checksum before using a
frame.

SCPI frame payloads contain command or response bytes directly. Capture frame
payloads contain the inner format below. Poll frames have no payload and clock
an ESP-to-Pico SCPI command back to the Pico when one is queued.

## Wireless capture payload

Every 500-byte outer capture payload begins with a 32-byte inner header:

| Offset | Size | Field |
| ---: | ---: | --- |
| 0 | 4 | Magic bytes `LBLB` (`0x424C424C` interpreted little-endian) |
| 4 | 1 | Format version, currently `1` |
| 5 | 1 | Instrument ID |
| 6 | 1 | Subtype: `1` metadata, `2` data |
| 7 | 1 | Reserved, zero |
| 8 | 4 | Capture sequence, little-endian `uint32_t` |
| 12 | 2 | Zero-based chunk index |
| 14 | 2 | Chunk count |
| 16 | 2 | Valid bytes following the header |
| 18 | 14 | Reserved, zero |
| 32 | 468 | Metadata/data followed by zero padding |

Instrument IDs are:

| ID | Instrument |
| ---: | --- |
| 1 | Logic analyser |
| 2 | Oscilloscope |
| 3 | MSO digital side |
| 4 | MSO analog side |

Each capture begins with one metadata frame. Its chunk index and count are zero,
and its 24-byte body consists of six little-endian `uint32_t` values:

| Body offset | Field |
| ---: | --- |
| 0 | Sample rate in Hz |
| 4 | Sample count |
| 8 | Channel count |
| 12 | Digital pin base or ADC channel |
| 16 | Trigger mode: `0` auto/off, `1` edge, `2` level |
| 20 | Data format: `1` packed LA `uint32_t`, `2` analog `uint16_t` |

Data follows in subtype-2 chunks of at most 468 bytes. Reassemble frames with
the same instrument ID and capture sequence in ascending chunk-index order,
using only `payload_len` bytes from each. An MSO wireless acquisition uses the
same capture sequence for its instrument-3 and instrument-4 series.

The ESP forwards complete 512-byte outer frames by UDP and may batch two frames
into a single 1,024-byte datagram. A receiver must therefore split datagrams in
512-byte units, validate each outer frame, then decode the inner payload.

## Network messages

- TCP port 5006 carries raw newline-terminated SCPI commands and their raw SCPI
  responses. It does not add a length wrapper around ordinary text responses.
- UDP port 5005 carries the outer capture frames described above.
- Send the ASCII datagram `LIBRELAB_UDP_REGISTER` to UDP port 5006 to register
  the sender as the unicast capture destination. Before registration, the ESP
  uses its configured destination, which defaults to broadcast.

There is no authentication, encryption, retransmission, or ordering layer on
the SCPI TCP/capture UDP services. Use sequence/chunk fields to detect loss or
reordering and operate the bridge only on a trusted network.

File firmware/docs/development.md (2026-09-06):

# Development guide

## Source ownership

The active RP2350 target follows a three-layer structure:

| Layer | Directory | Responsibility |
| --- | --- | --- |
| Application | `src/application/` | SCPI command table, argument validation, response formatting, feature-facing state |
| System | `src/system/` | Hardware-independent instruments, buses, capture orchestration, transport policy |
| Platform | `src/platform/` | Pico SDK, GPIO, ADC, PIO, DMA, UART/I2C/SPI, USB, LED, and ESP-link details |
| Utilities | `src/util/` | Logging, errors, SI-prefix constants, and circular buffer |

The ESP32-C3 is a separate ESP-IDF application under `esp_firmware/`. The
libsigrok adapter under `tools/sigrok/` is host software and is not linked into
either embedded image.

## Adding or changing a SCPI feature

1. Put portable state and operations in the system layer when the feature has a
   meaningful hardware-independent boundary.
2. Put Pico SDK calls in the platform layer. Do not make application command
   handlers own DMA channels, PIO state machines, or SDK peripheral handles.
3. Add small command adapters in `src/application/` or
   `src/application/protocol/`. Validate every required parameter and translate
   failures to the appropriate SCPI error.
4. Register commands in `g_SCPI_COMMANDS` in
   `src/application/protocol/common.c`.
5. Add new `.c` files and required Pico SDK libraries to the root
   `CMakeLists.txt`.
6. Reset new instrument state from `protocol_reset()` when `*RST` should affect
   it.
7. Add tests, update `docs/scpi-reference.md`, and update the corresponding
   feature/data-format documentation.

Keep query results stable and machine-readable. Use decimal integers or
documented CSV for small metadata and SCPI arbitrary blocks for binary data.
Do not mix diagnostic logging into the CDC SCPI channel.

## Runtime constraints

The firmware uses a cooperative main loop, not an RTOS. `protocol_task()`
services TinyUSB, polls wireless SCPI, advances the pattern generator, and emits
capture stream frames. Long waits inside a command handler stop all of those
activities. New trigger or peripheral waits should therefore be bounded and
should report an execution error on timeout.

Static buffers are deliberately used for deterministic embedded memory. Check
both element capacity and transport-message capacity before increasing a limit.
For example, the pattern store is much larger than the 1,024-byte SCPI input
buffer, and the ESP bridge carries only 500 payload bytes per SPI frame.

## Hardware resource rules

There is no central GPIO, DMA, PIO, PWM-slice, ADC, or peripheral ownership
manager. Before adding a resource:

- compare it with the table in [hardware resources](hardware.md);
- reject incompatible concurrent use when practical;
- release DMA channels and PIO state machines on stop/error paths;
- restore pins to a safe input state when an output feature stops;
- document fixed pins and conflicts;
- ensure an input is 3.3 V-safe and analog inputs remain within their range.

PIO0 state machine 0 is currently used by the logic analyser and state machine
1 by the pattern generator. Captures and output also consume DMA channels.
The ADC engine is shared by DSO and MSO.

## Changing the wireless protocol

The 512-byte outer frame exists in both `src/platform/esp_spi_bridge.*` and
`esp_firmware/main/main.c`. The versioned inner capture payload is produced in
`src/system/transport.c`. When changing it:

1. Preserve explicit byte offsets and little-endian encoding; do not transmit a
   native C struct whose padding depends on a compiler.
2. Increment the inner version for incompatible changes.
3. Update validation on the ESP and receiver tooling.
4. Build both firmware projects.
5. Update [data formats](data-formats.md) with every changed field.
6. Test lost, duplicate, reordered, maximum-size, and malformed frames.

## Naming and public identity

Use `LibreLab` for user-facing prose and `librelab` for targets, paths, protocol
tokens, and identifiers. The current USB/SCPI identity is intentionally
documented and should be changed only as a coordinated compatibility decision.
Do not rename vendored upstream projects or their license notices.

## Style and static analysis

The RP2350 code is C11; the project also enables C++17 for Pico SDK compatibility.
Follow `src/.clang-format` and `src/.clang-tidy` for changed first-party source.
Useful local checks, when the tools are installed, are:

```bash
clang-format --dry-run --Werror path/to/changed.c path/to/changed.h
cmake --build build-pico2 --target librelab_pico
make -C tools/sigrok/librelab-pico test
```

Avoid formatting or mechanically rewriting vendored code under `lib/`.

## Generated and vendored files

- `build*` directories, ESP `sdkconfig`, binary outputs, and Python caches are
  generated and should not be hand-edited.
- `lib/` contains third-party source with its own licenses.
- `esp_firmware/dependencies.lock` records the resolved ESP component graph and
  should change only when dependencies are intentionally updated.

## Review checklist

- Both success and failure paths release hardware resources.
- Bounds account for bytes versus words and include transport overhead.
- SCPI setters reject changes that are unsafe while a feature is active.
- A query documents its exact field order and units.
- Binary formats state endianness, packing, and valid length.
- Trigger waits and bus waits have intentional timeout behavior.
- Default pins do not silently conflict, or the conflict is rejected/documented.
- `*RST`, disconnect, stop, and repeated initialization are safe.
- Root README, command reference, feature guide, and tests agree with source.

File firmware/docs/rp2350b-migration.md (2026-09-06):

# RP2350B PCB and firmware migration

## Verified conclusion

The RP2350B package can eliminate the current LibreLab **pad-level** conflicts.
It exposes 48 GPIOs instead of the RP2350A's 30, and the added pins have UART,
SPI, I2C, PWM, and PIO alternate functions. A conflict-free PCB is therefore
feasible.

This is not automatic and RP2350B is not a drop-in target for the current
binary. The PCB must route a non-overlapping map and the firmware must select
that map. Shared hardware engines and firmware ownership constraints continue
to exist even when every signal has a different pad.

## Package differences that affect LibreLab

| Property | RP2350A / current Pico 2 | RP2350B / future PCB | Consequence |
| --- | --- | --- | --- |
| Package | QFN-60 | QFN-80 | A new PCB footprint and escape routing are required. |
| Bank-0 GPIO | 30, GPIO0–29 | 48, GPIO0–47 | B has 18 extra pads for separating functions. |
| ADC inputs | ADC0–3 on GPIO26–29 | ADC0–7 on GPIO40–47 | The present `26 + channel` calculation is invalid on B. |
| PWM outputs | 16 channels | 24 channels | B adds slices 8–11, but paired A/B outputs still share a slice. |
| UART/SPI/I2C controllers | 2 / 2 / 2 | 2 / 2 / 2 | B adds routes, not controller instances. |
| PIO-visible pins | GPIO0–29 fit the low window | Per PIO: GPIO0–31 or GPIO16–47 | High pins require selecting the PIO base and keeping a PIO's active pins in one window. |

Official references:

- [Raspberry Pi microcontroller chip comparison](https://www.raspberrypi.com/documentation/microcontrollers/microcontroller-chips.html)
- [RP2350 datasheet](https://datasheets.raspberrypi.com/rp2350/rp2350-datasheet.pdf), especially the pin-function and ADC chapters
- [Pico SDK PIO API](https://www.raspberrypi.com/documentation/pico-sdk/hardware.html), including `pio_set_gpio_base()`
- [Pico SDK RP2350 platform definition](https://github.com/raspberrypi/pico-sdk/blob/master/src/rp2350/pico_platform/include/pico/platform.h)

## Why the current firmware is RP2350A-only

The current documented pin conflicts are real for the current build. They are
not all unavoidable properties of the RP2350A; they result from fitting many
functions into the selected fixed/default routes without a global owner.

The source also contains explicit A assumptions:

- builds use `PICO_BOARD=pico2`, whose SDK board header sets `PICO_RP2350A=1`;
- LA, MSO, pattern, test-signal, I2C, and SPI paths contain GPIO29/30 limits;
- the internal ADC accepts channels 0–3 and maps them to GPIO26–29;
- UART, I2C, SPI, logging, and ESP-link defaults are fixed in their modules;
- PIO0 is used by both LA/MSO digital capture and pattern output, but no code
  selects PIO's GPIO16–47 window.

Consequently, merely fitting an RP2350B or changing the CMake board name would
not enable the extra pads and would route analog acquisition incorrectly.

## Candidate conflict-free allocation

This allocation demonstrates feasibility; it is a routing input, not an
approved schematic pinout. Power, ground, USB, flash, debug, clock, analog
layout, HSTX, and manufacturing constraints still require schematic review.

| Function | Candidate RP2350B GPIO | Reason |
| --- | --- | --- |
| Logging UART0 | TX 0, RX 1 | Retains the current debug connector convention. |
| ESP bridge SPI0 + READY | SCK 2, TX 3, RX 4, CS 5, READY 6 | Retains the existing two-board bridge protocol. |
| Status LED | 7 | Keeps it outside instrument banks; define it in the board header. |
| UART gateway UART1 | TX 8, RX 9 | Valid UART1 alternate-function pair, separate from SPI0. |
| I2C gateway I2C1 | SDA 10, SCL 11 | Valid I2C1 pair, separate from logging and READY. |
| Square test output | 12 | PWM slice 6A. |
| PWM “analog” test output | 14 | PWM slice 7A, so it does not share the square output's slice. |
| LA/MSO digital bank | 16–23 | Eight consecutive inputs in the PIO high window. |
| SPI gateway SPI1 | RX 28, CS 29, SCK 30, TX 31 | One coherent SPI1 route, outside the capture bank. |
| Pattern-generator bank | 32–39 | Eight consecutive outputs in the same PIO high window as LA. |
| Internal ADC | ADC0–7 on 40–47 | The RP2350B's fixed analog-capable pins. |

GPIO13, GPIO15, and GPIO24–27 remain available in this example. All listed
signal pads are distinct, and both PIO0 banks lie inside GPIO16–47. Features
which share an engine still cannot necessarily run together: LA and MSO use the
same capture backend, DSO and MSO share the ADC, and LA/pattern share PIO0 even
though they use different state machines.

Before committing this allocation, verify every signal against the RP2350B
pin-function table and the completed schematic. In particular, reserve any
pins needed by board power control, voltage monitoring, external analog
frontends, or production test.

## Required firmware work

1. Add a custom Pico SDK board definition, for example
   `boards/librelab_rp2350b.h`. It must select `rp2350`, define
   `PICO_RP2350A` as `0`, and describe the real flash, LED, and board defaults.
2. Move every board pin into one board-profile header. Avoid duplicating numeric
   GPIO constants across platform and application modules.
3. Replace hard-coded `29`, `30`, and GPIO-count checks with package/profile
   limits. Validate the alternate function as well as the numeric range.
4. Make the ADC backend package-aware: B has eight channels at GPIO40–47.
   Update DSO/MSO SCPI validation, capability reporting, metadata, and tests.
5. Set PIO0's GPIO base to `16` before loading/configuring programs that use the
   candidate LA and pattern banks. The SDK must build with
   `PICO_PIO_USE_GPIO_BASE=1`, which is normally enabled for a correctly defined
   B target. Treat the base as PIO-wide state, not state-machine-local state.
6. Apply the new UART1, I2C1, SPI1, PWM, LED, and ESP-link mappings. Keep the
   ESP32-C3 Kconfig pins synchronized if the bridge wiring changes.
7. Add a central GPIO/peripheral owner so invalid concurrent combinations fail
   before a module changes pin mux or direction.
8. Build A and B targets in CI. On B hardware, test all 48 digital pads, all
   routed ADC inputs, simultaneous non-conflicting gateways, both test outputs,
   maximum-width LA and pattern banks, USB, Wi-Fi, SWD, and reset/BOOTSEL paths.

## Acceptance criteria for declaring RP2350B supported

- The build uses the LibreLab RP2350B board definition, not `pico2`.
- Compile-time assertions report 48 bank-0 GPIOs and the intended ADC mapping.
- The generated schematic pin table and firmware board profile agree exactly.
- No default GPIO is assigned to more than one simultaneously advertised
  function, and conflicts on shared engines are rejected with a clear error.
- LA and pattern generation pass on GPIOs above 31 with PIO base 16.
- DSO/MSO capture the actual GPIO40–47 analog inputs; GPIO26–29 are never
  documented or initialized as analog inputs on B.
- The complete hardware validation matrix passes on a populated PCB.

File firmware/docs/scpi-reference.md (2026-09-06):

# SCPI command reference

This page lists every command registered by the current Pico 2/RP2350A
firmware. The command table in `src/application/protocol/common.c` is the source
of truth.

All GPIO and ADC ranges here describe that current image. The planned RP2350B
port will require package-aware command limits; see
[RP2350B migration](rp2350b-migration.md).

## Syntax and responses

- Commands are case-insensitive. Capital letters shown below are the shortest
  accepted spelling; lowercase letters complete the long spelling.
- End each program message with LF (`\n`) or CRLF (`\r\n`).
- Separate parameters with commas. Boolean parameters accept the SCPI boolean
  forms supported by the bundled parser, including `0`/`1` and `OFF`/`ON`.
- Write ordinary integers in decimal. SCPI non-decimal notation is `#H3C` for
  hexadecimal, `#Q74` for octal, or `#B111100` for binary; C-style `0x3C` is
  not the documented input syntax.
- Text and numeric queries end in a newline. Binary queries return a SCPI
  definite-length arbitrary block, described in [data formats](data-formats.md).
- The input buffer is 1,024 bytes and the SCPI error queue holds 16 entries.
- A command with no documented response is silent on success. Inspect
  `SYSTem:ERRor?` after a failed operation.

Examples use legal abbreviated spellings:

```text
LA:CONF:PINC 4
LA:CONF:PINC?
```

## IEEE 488.2 and required system commands

| Command | Parameters / response | Meaning |
| --- | --- | --- |
| `*RST` | none | Reset LA, DSO, MSO, and pattern-generator state. It does not reboot the board or reset gateway/transport configuration. |
| `*IDN?` | `FOSSASIA,LibreLab Pico,1.0,v0.1.0` | Device identification. |
| `*TST?` | integer | Parser core self-test response. |
| `*CLS` | none | Clear standard status and the SCPI error queue. |
| `*ESE <mask>` / `*ESE?` | event-status enable byte | Set/query the standard event-status enable register. |
| `*ESR?` | event-status byte | Read and clear the standard event-status register. |
| `*OPC` / `*OPC?` | query returns `1` | Standard operation-complete commands. Operations in this firmware are synchronous. |
| `*SRE <mask>` / `*SRE?` | service-request enable byte | Set/query the service-request enable register. |
| `*STB?` | status byte | Read the status byte. |
| `*WAI` | none | Standard wait-to-continue command; there is no background command queue. |
| `SYSTem:ERRor[:NEXT]?` | `code,"message"` | Pop the oldest error, or return no-error when empty. `SYST:ERR?` is the usual short form. |
| `SYSTem:ERRor:COUNt?` | integer | Number of queued SCPI errors. |
| `SYSTem:VERSion?` | text | SCPI language version reported by the bundled parser. |

## Communication transport

| Command | Parameters / response | Meaning |
| --- | --- | --- |
| `COMM:TRANsport <USB\|WIFI\|WIRELESS\|AUTO>` | mode | Select the capture/SCPI transport. `WIRELESS` is an alias for `WIFI`. Selecting Wi-Fi or auto initializes the Pico-side ESP bridge. |
| `COMM:TRANsport?` | `USB`, `WIFI`, or `AUTO` | Return the configured mode. |
| `COMM:WIFI:STATus?` | `effective,sent,dropped,timeouts` | Return effective-mode flag and Pico-side SPI-frame counters. In forced `WIFI` mode, `effective` reflects the selected mode, not proof that an ESP is responding. |

The boot default is `USB`. A newly booted device must therefore receive
`COMM:TRAN AUTO` or `COMM:TRAN WIFI` over USB before it polls the ESP for TCP
commands.

## UART gateway

The UART gateway is fixed at 8 data bits, no parity, one stop bit. Binary input
and output use arbitrary blocks. See [bus gateways](features/bus-gateways.md).

| Command | Parameters / response | Meaning |
| --- | --- | --- |
| `BUS:UART:OPEN` / `BUS:UART:OPEN?` | query returns boolean | Open UART1, or query its open state. |
| `BUS:UART:CLOSe` | none | Close the UART gateway. |
| `BUS:UART:CONFigure:BUS <1>` / `BUS:UART:CONFigure:BUS?` | bus number | Select/query the only supported bus. Set while closed. |
| `BUS:UART:CONFigure:BAUD <1200..3000000>` / `BUS:UART:CONFigure:BAUD?` | bit/s | Set/query baud while closed. Default 115,200. |
| `BUS:UART:CONFigure:TIMEout <0..60000>` / `BUS:UART:CONFigure:TIMEout?` | milliseconds | Set/query read/flush timeout. Default 100 ms. |
| `BUS:UART:WRITe <block>` | bytes written | Queue up to 512 bytes for transmission. |
| `BUS:UART:READ? [maximum]` | binary block | Read available bytes, up to 512. The optional maximum defaults to 512 and larger values are clamped. |
| `BUS:UART:AVAILable?` | byte count | Return the RX bytes currently buffered. |
| `BUS:UART:CLEar` | none | Clear buffered receive data. |
| `BUS:UART:FLUSh` | none | Wait for pending transmit data using the configured timeout. |
| `BUS:UART:TRANsact? <block>` | binary block | Clear RX, write and flush, then read until 512 bytes, 5 ms of RX inactivity, or the configured timeout. |

## I2C gateway

| Command | Parameters / response | Meaning |
| --- | --- | --- |
| `BUS:I2C:OPEN` / `BUS:I2C:OPEN?` | query returns boolean | Open/query the configured I2C master. |
| `BUS:I2C:CLOSe` | none | Close the I2C gateway. |
| `BUS:I2C:CONFigure:BUS <0\|1>` / `BUS:I2C:CONFigure:BUS?` | bus number | Set/query bus while closed. Bus 0 uses GPIO0/1; bus 1 uses GPIO6/7. |
| `BUS:I2C:CONFigure:RATE <1000..1000000>` / `BUS:I2C:CONFigure:RATE?` | Hz | Set/query clock rate while closed. Default 100 kHz. |
| `BUS:I2C:CONFigure:ADDRess <8..119>` / `BUS:I2C:CONFigure:ADDRess?` | 7-bit address | Set/query the current target address. Default `0x3C` (60). |
| `BUS:I2C:CONFigure:TIMEout <1..60000>` / `BUS:I2C:CONFigure:TIMEout?` | milliseconds | Set/query transfer timeout. Default 100 ms. |
| `BUS:I2C:SCAN?` | comma-separated hex | Probe usable 7-bit addresses and return values such as `3C,68`. |
| `BUS:I2C:WRITe <block>` | bytes written | Write up to 512 bytes and issue STOP. |
| `BUS:I2C:READ? <1..512>` | binary block | Read the requested number of bytes. |
| `BUS:I2C:TRANsact? <write-block>,<1..512>` | binary block | Write without STOP, then repeated-start and read. |

## SPI gateway

These commands are registered, but the current build has a bus-number mismatch:
the command layer only accepts bus `1` and the system layer exposes logical bus
`0`. `BUS:SPI:OPEN` consequently fails with an execution error until that defect
is fixed.

| Command | Parameters / response | Meaning once the bus mismatch is fixed |
| --- | --- | --- |
| `BUS:SPI:OPEN` / `BUS:SPI:OPEN?` | query returns boolean | Open/query SPI1. |
| `BUS:SPI:CLOSe` | none | Close the SPI gateway. |
| `BUS:SPI:CONFigure:BUS <1>` / `BUS:SPI:CONFigure:BUS?` | bus number | Set/query the command-layer bus while closed. |
| `BUS:SPI:CONFigure:RATE <1000..50000000>` / `BUS:SPI:CONFigure:RATE?` | Hz | Set/query clock rate while closed. Default 1 MHz. |
| `BUS:SPI:CONFigure:MODE <0..3>` / `BUS:SPI:CONFigure:MODE?` | mode | Set/query CPOL/CPHA mode while closed. Default mode 0. |
| `BUS:SPI:CONFigure:DUMMY <0..255>` / `BUS:SPI:CONFigure:DUMMY?` | byte value | Set/query the byte transmitted during read clocks. Default `0xFF`. |
| `BUS:SPI:WRITe <block>` | bytes written | Assert CS and write up to 512 bytes. |
| `BUS:SPI:READ? <1..512>` | binary block | Read while sending the dummy byte. |
| `BUS:SPI:EXCHange? <block>` | binary block | Full-duplex transfer; response length equals input length. |
| `BUS:SPI:TRANsact? <write-block>,<1..512>` | binary block | Write a command then read while keeping the transaction selected. |

All SPI transfers are 8-bit, MSB-first, and use an active-low GPIO13 CS.

## Logic analyser

| Command | Parameters / response | Meaning |
| --- | --- | --- |
| `LA:CONFigure:PINBase <gpio>` / `LA:CONFigure:PINBase?` | GPIO | First of the consecutive input pins. Default 16. |
| `LA:CONFigure:PINCount <1..8>` / `LA:CONFigure:PINCount?` | channels | Number of consecutive pins. Default 2. |
| `LA:CONFigure:SAMPles <1..65536>` / `LA:CONFigure:SAMPles?` | samples | Samples per finite capture. Streaming additionally limits this to 4,096. Default 96. |
| `LA:CONFigure:DIVider <1..16777215>` / `LA:CONFigure:DIVider?` | integer divider | PIO clock divider. Default 1. |
| `LA:CONFigure:RATE?` | samples/s | Return `clk_sys / divider`. |
| `LA:CONFigure:TRIGger:PIN <gpio>` / `LA:CONFigure:TRIGger:PIN?` | GPIO | Set/query trigger GPIO. Default 16. |
| `LA:CONFigure:TRIGger:LEVel <bool>` / `LA:CONFigure:TRIGger:LEVel?` | boolean | Desired high/low trigger level. Default high. |
| `LA:CONFigure:TRIGger:MODE <AUTO\|EDGE\|LEVEL>` / `LA:CONFigure:TRIGger:MODE?` | mode | Set/query trigger mode. Default `AUTO`. `EDGE` uses the selected level as the destination level. |
| `LA:INITiate` | none | Perform and retain a synchronous capture. Triggered modes can wait indefinitely. |
| `LA:FETCh[:DATa]?` | binary block | Return the retained capture; error if none is ready. `LA:FETC?` and `LA:FETC:DATA?` are equivalent. |
| `LA:READ?` | binary block | Initiate, then fetch one capture. |
| `LA:STATus?` | `0`, `1`, or `2` | `0` idle, `1` capture ready, `2` busy/streaming. |
| `LA:METadata?` | six CSV integers | `sample_rate,pin_base,pin_count,sample_count,word_count,bits_per_word`. |
| `LA:STREAM:STARt` | none | Start continuous frames and stop DSO streaming. |
| `LA:STREAM:STOP` | none | Stop continuous frames. |
| `LA:STREAM:STATus?` | three CSV integers | `enabled,sequence,overruns`. |
| `LA:WIFI:READ?` | sequence number | Force Wi-Fi mode, capture once, send wireless metadata/data frames, and return the capture sequence over SCPI. |

## Oscilloscope

| Command | Parameters / response | Meaning |
| --- | --- | --- |
| `DSO:CONFigure:CHANnel <0..3>` / `DSO:CONFigure:CHANnel?` | ADC channel | Select/query ADC0–ADC3. Default 0. |
| `DSO:CONFigure:GPIO?` | GPIO | Return 26–29 for the selected ADC channel. |
| `DSO:CONFigure:SAMPles <1..4096>` / `DSO:CONFigure:SAMPles?` | samples | Set/query capture length. Default 1,024. |
| `DSO:CONFigure:RATE <1..500000>` / `DSO:CONFigure:RATE?` | samples/s | Set/query sample rate. Default 100 ksample/s. |
| `DSO:CONFigure:TRIGger:LEVel <0..4095>` / `DSO:CONFigure:TRIGger:LEVel?` | ADC counts | Set/query raw 12-bit threshold. Default 2,048. |
| `DSO:CONFigure:TRIGger:MODE <OFF\|LEVEL\|EDGE>` / `DSO:CONFigure:TRIGger:MODE?` | mode | Set/query trigger mode. Default `OFF`. |
| `DSO:CONFigure:TRIGger:SLOPe <RISE\|RISING\|FALL\|FALLING>` / `DSO:CONFigure:TRIGger:SLOPe?` | slope | Set/query trigger direction. Query returns the canonical stored spelling. |
| `DSO:INITiate` | none | Perform and retain a synchronous capture. A finite triggered capture has no timeout. |
| `DSO:FETCh[:DATa]?` | binary block | Return the retained capture. |
| `DSO:READ?` | binary block | Initiate, then fetch one capture. |
| `DSO:STATus?` | `0`, `1`, or `2` | `0` idle, `1` capture ready, `2` busy/streaming. |
| `DSO:STREAM:STARt` | none | Start continuous frames and stop LA streaming. |
| `DSO:STREAM:STOP` | none | Stop continuous frames. |
| `DSO:STREAM:STATus?` | three CSV integers | `enabled,sequence,overruns`. |
| `DSO:WIFI:READ?` | sequence number | Force Wi-Fi mode, capture once, send wireless metadata/data frames, and return its sequence. |

## Mixed-signal capture

| Command | Parameters / response | Meaning |
| --- | --- | --- |
| `MSO:CONFigure:DIGital:PINBase <gpio>` / `MSO:CONFigure:DIGital:PINBase?` | GPIO | First consecutive digital pin. Default 16. |
| `MSO:CONFigure:DIGital:PINCount <1..8>` / `MSO:CONFigure:DIGital:PINCount?` | channels | Digital channel count. Default 1. |
| `MSO:CONFigure:ANALog:CHANnel <0..3>` / `MSO:CONFigure:ANALog:CHANnel?` | ADC channel | Analog channel. Default 0/GPIO26. |
| `MSO:CONFigure:SAMPles <1..4096>` / `MSO:CONFigure:SAMPles?` | samples per side | Shared digital/analog capture length. Default 1,024. |
| `MSO:CONFigure:RATE <1..500000>` / `MSO:CONFigure:RATE?` | samples/s | Shared requested sample rate. Default 500 ksample/s. |
| `MSO:CONFigure:TRIGger:PIN <gpio>` / `MSO:CONFigure:TRIGger:PIN?` | GPIO | Digital trigger GPIO. Default 16. |
| `MSO:CONFigure:TRIGger:LEVel <bool>` / `MSO:CONFigure:TRIGger:LEVel?` | boolean | Destination/high-low trigger level. Default high. |
| `MSO:CONFigure:TRIGger:MODE <EDGE\|LEVEL>` / `MSO:CONFigure:TRIGger:MODE?` | mode | Digital trigger mode. Default `EDGE`. |
| `MSO:INITiate` | none | Capture both streams with a shared trigger; trigger wait timeout is one second. |
| `MSO:FETCh:DIGital?` / `MSO:FETCh:ANALog?` | binary block | Fetch the two parts of the same retained capture. |
| `MSO:READ:DIGital?` / `MSO:READ:ANALog?` | binary block | Each command starts a new capture and returns only that side. Use `INITiate` plus two `FETCh` queries when alignment matters. |
| `MSO:STATus?` | `0`, `1`, or `2` | `0` idle, `1` capture ready, `2` busy. |
| `MSO:METadata?` | ten CSV integers | `rate,samples,digital_base,digital_count,digital_words,bits_per_word,analog_channel,analog_gpio,digital_offset_ns,analog_offset_ns`. Offsets are currently zero placeholders. |
| `MSO:WIFI:READ?` | sequence number | Force Wi-Fi mode and send paired digital and analog captures with a common sequence. |

## Pattern generator

| Command | Parameters / response | Meaning |
| --- | --- | --- |
| `PG:CONFigure:PINS <base>,<1..8>` / `PG:CONFigure:PINS?` | query: `base,count` | Configure consecutive outputs. Default GPIO16, one pin. |
| `PG:CONFigure:RATE <1..75000000>` / `PG:CONFigure:RATE?` | samples/s | Set/query output sample rate. The derived PIO divider must also fit 1–65,536. Default 2 ksample/s. |
| `PG:CONFigure:MODE <ONCE\|LOOP>` / `PG:CONFigure:MODE?` | mode | Select one-shot or repeating output. Default `ONCE`. |
| `PG:DATA <block>` | none | Upload little-endian packed 32-bit words. Capacity is 16,384 words, but one SCPI message is effectively limited by the 1,024-byte input buffer. |
| `PG:STARt` | none | Start DMA/PIO output; data must have been uploaded. |
| `PG:STOP` | none | Stop output. |
| `PG:STATus?` | four CSV integers | `running,rate,pin_count,pattern_words`. |
| `PG:UNDerrun?` | count | Return the underrun counter. |

## Test signals

| Command | Parameters / response | Meaning |
| --- | --- | --- |
| `TEST:SQUare <bool>` / `TEST:SQUare?` | query returns boolean | Enable/disable/query the default GPIO15, 1 kHz, 50% digital square wave. |
| `TEST:SQUare:CONFigure <gpio>,<frequency_hz>` | none | Start a square wave on GPIO0–29 at a positive frequency. |
| `TEST:SQUare:PIN?` | GPIO | Return configured square-wave pin. |
| `TEST:SQUare:FREQuency?` | Hz | Return achieved square-wave frequency. |
| `TEST:ANALog <bool>` / `TEST:ANALog?` | query returns boolean | Enable/disable/query the default GPIO13, 1 kHz, 50% PWM output. This is not a DAC output. |
| `TEST:ANALog:CONFigure <gpio>,<frequency_hz>,<duty_permille>` | none | Start PWM; duty is 0–1,000, where 500 is 50%. |
| `TEST:ANALog:PIN?` | GPIO | Return configured PWM pin. |
| `TEST:ANALog:FREQuency?` | Hz | Return achieved PWM frequency. |
| `TEST:ANALog:DUTY?` | permille | Return duty in thousandths. |

## Errors and blocking behavior

Missing parameters, out-of-range values, invalid state, and hardware failures are
reported through the standard SCPI queue. During development, a useful pattern
is:

```text
*CLS
LA:CONF:PINC 99
SYST:ERR?
SYST:ERR:COUNT?
```

Commands are processed cooperatively in the main loop, but finite captures are
synchronous. In particular, non-auto LA triggers and finite triggered DSO
captures can prevent all further SCPI processing when the trigger never arrives.
Resetting or power-cycling the board is then required.

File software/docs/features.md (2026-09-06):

# Feature Map

## Capture Workspace

The main workspace shows a channel rail, a timeline canvas, session tabs, capture status, and a right-side inspector. It supports three modes:

- Logic: digital channels only.
- Scope: analog channels only.
- MSO: digital and analog channels together.

LibreLab Studio capture workspace

## Waveform Viewer

Implemented interactions:

- mouse wheel zoom around cursor;
- shift-wheel or horizontal wheel pan;
- pointer drag pan;
- click to place A/B markers;
- Fit button to reset the view.

The viewer draws digital transitions as stepped traces and analog signals as per-pixel min/max columns so large captures remain responsive.

## Protocol Analyzers

The analyzer panel currently exposes a simulated I2C decoder lane. The UI consumes generic `DecoderAnnotation` records, so future libsigrokdecode support can add protocols without rewriting the waveform renderer.

LibreLab Studio analyzer panel

## Measurements

The measurement panel computes current-session duration, sample count, edge count, and first-digital-channel frequency estimate. Timeline A/B marker deltas are displayed in the viewport HUD.

## Outputs

The output panel includes simulated controls for:

- pattern generator;
- square-wave output;
- PWM output.

These are UI placeholders wired to local state. The hardware engine should later route them through explicit output-control APIs.

## Bus Console

The bus panel provides simulated UART, I2C, and SPI console modes. The current flow echoes messages locally, which gives us a stable GUI workflow for tests before real bus transport is connected.

LibreLab Studio bus console

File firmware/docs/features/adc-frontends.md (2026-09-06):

# Internal ADC frontend

The ADC frontend layer separates instrument logic from acquisition hardware. A
backend registers a capability table and callbacks for configure, arm, start,
wait, abort, one-shot read, busy state, and channel-to-GPIO mapping.

## Backend registry

The frontend type enum reserves values for:

```text
NONE = 0
INTERNAL = 1
EXTERNAL_PARALLEL = 2
```

`PLATFORM_init()` registers the internal backend. DSO and MSO explicitly select
it. No external frontend implementation is included.

## Current RP2350A internal ADC backend

| Capability | Value |
| --- | --- |
| Channels | 0–3 |
| GPIO mapping | channel + 26 |
| Sample width | 12 bits |
| Sample rate | 1–500,000 samples/s |
| Maximum capture | 4,096 samples |
| Transfer | ADC FIFO to `uint16_t` RAM through DMA |

The backend can run a blocking capture or split it into arm/start/wait phases,
which MSO uses to coordinate analog and digital engines. Adding another frontend
requires a complete driver, capture engine, registration, selection mechanism,
hardware resource map, and tests; placeholder hardware APIs are intentionally
not kept in the production tree.

## RP2350B note

RP2350B exposes ADC0–ADC7 on GPIO40–GPIO47. The current backend is not
package-aware: it accepts only channels 0–3 and computes GPIO as `26 + channel`.
That mapping is correct for RP2350A and wrong for RP2350B. The future board port
must use a package-specific ADC base/count (and decide whether the public SCPI
range expands to all eight inputs) before DSO or MSO is enabled.

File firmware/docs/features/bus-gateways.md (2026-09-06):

# UART, I2C, and SPI gateways

The gateway commands let a USB or Wi-Fi host use RP2350 peripheral controllers
as binary-safe SCPI buses. Transfers use SCPI arbitrary blocks and are limited
to 512 bytes.

## UART gateway

The gateway exposes UART1 on GPIO4 TX and GPIO5 RX in fixed 8N1 format. UART0 is
reserved for logs.

| Setting | Default | Range |
| --- | --- | --- |
| Bus | 1 | Only 1 |
| Baud | 115,200 | 1,200–3,000,000 |
| Read/flush timeout | 100 ms | 0–60,000 ms; zero disables transact wait timeout |
| Buffers | 512 bytes RX + 512 bytes TX | Fixed |

Set bus and baud only while closed. The timeout may be changed while open.
`TRANsact?` clears RX, writes and flushes, then reads until 512 bytes, 5 ms of RX
inactivity, or the configured timeout.

```text
BUS:UART:CONF:BUS 1
BUS:UART:CONF:BAUD 115200
BUS:UART:CONF:TIME 250
BUS:UART:OPEN
BUS:UART:WRIT #15hello
BUS:UART:READ? 64
BUS:UART:CLOSE
```

GPIO4/5 conflicts with the default ESP bridge connection.

## I2C gateway

The gateway is a 7-bit I2C master. Internal pull-ups are enabled.

| Setting | Default | Range |
| --- | --- | --- |
| Bus | 0 | 0 or 1 |
| Pins | Bus 0: GPIO0/1; bus 1: GPIO6/7 | Fixed by bus |
| Address | `0x3C` | `0x08`–`0x77` |
| Rate | 100 kHz | 1 kHz–1 MHz |
| Timeout | 100 ms | 1–60,000 ms |

Set bus and rate only while closed. Address and timeout may be changed while
open. `SCAN?` probes non-reserved addresses and returns uppercase two-digit hex
addresses separated by commas. `TRANsact?` performs a no-stop write followed by
a repeated-start read.

```text
BUS:I2C:CONF:BUS 1
BUS:I2C:CONF:RATE 400000
BUS:I2C:CONF:ADDR 60
BUS:I2C:OPEN
BUS:I2C:SCAN?
BUS:I2C:READ? 16
BUS:I2C:CLOSE
```

I2C0 conflicts with logging UART0. I2C1 conflicts with the ESP READY pin.

## SPI gateway

The intended hardware backend is SPI1, mode 0, MSB-first, active-low CS:

| Signal | GPIO |
| --- | --- |
| SCK | 10 |
| MOSI/TX | 11 |
| MISO/RX | 12 |
| CS | 13 |

The intended configurable rate is 1 kHz–50 MHz, mode 0–3, and dummy byte
0–255. Write, read, full-duplex exchange, and write-then-read transaction
operations are implemented.

### Current integration defect

The SCPI gateway defaults to and only accepts bus number `1`, while the system
SPI layer exposes one logical bus numbered `0` and maps it to hardware SPI1.
Consequently `BUS:SPI:OPEN` currently returns an execution error. The command
set is compiled but should be considered unavailable until the two numbering
conventions are aligned.

GPIO13 also conflicts with the default PWM “analog” test output.

## Arbitrary-block example

A definite-length block is `#<digit-count><payload-length><payload>`. For three
bytes `0x9F 0x00 0x01`, send the bytes:

```text
#13\x9f\x00\x01
```

The `\xNN` notation above describes bytes; do not send the four literal ASCII
characters. A Python transaction looks like:

```python
def block(payload: bytes) -> bytes:
    length = str(len(payload)).encode()
    return b"#" + str(len(length)).encode() + length + payload

port.write(b"BUS:I2C:TRAN? " + block(b"\x00") + b",2\n")
```

All binary query results are returned as definite-length blocks.

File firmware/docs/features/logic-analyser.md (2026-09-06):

# Logic analyser

The logic analyser samples 1–8 consecutive RP2350 GPIO pins with PIO0 state
machine 0 and transfers packed samples to RAM with DMA.

The GPIO ranges below are current RP2350A firmware limits. RP2350B can use
GPIO0–47 after the application limits are made package-aware. A group above
GPIO31 also requires PIO0 to select its GPIO16–47 window; see
[RP2350B migration](../rp2350b-migration.md).

## Defaults and limits

| Setting | Default | Range |
| --- | --- | --- |
| First GPIO | 16 | 0–29, with the full group ending by GPIO29 |
| Channel count | 2 | 1–8 |
| Samples | 96 | 1–65,536 finite; at most 4,096 for streaming |
| PIO clock divider | 1 | 1–16,777,215 |
| Trigger pin | 16 | 0–29 |
| Trigger level | High (`1`) | Low or high |
| Trigger mode | `AUTO` | `AUTO`, `LEVEL`, `EDGE` |

The sample-rate query returns `clk_sys / divider`. Divider `1` therefore samples
once per PIO instruction at the system clock rate.

## Commands

- `LA:CONFigure:PINBase <gpio>` and query form
- `LA:CONFigure:PINCount <count>` and query form
- `LA:CONFigure:SAMPles <count>` and query form
- `LA:CONFigure:DIVider <divider>` and query form
- `LA:CONFigure:RATE?`
- `LA:CONFigure:TRIGger:PIN <gpio>` and query form
- `LA:CONFigure:TRIGger:LEVel <bool>` and query form
- `LA:CONFigure:TRIGger:MODE <AUTO|LEVEL|EDGE>` and query form
- `LA:INITiate`
- `LA:FETCh[:DATa]?`
- `LA:READ?`
- `LA:STATus?`
- `LA:METadata?`
- `LA:STREAM:STARt`, `LA:STREAM:STOP`, `LA:STREAM:STATus?`
- `LA:WIFI:READ?`

See the [complete command reference](../scpi-reference.md) for responses and
error behavior.

## Capture lifecycle

- `INITiate` performs a capture and stores it in RAM.
- `FETCh?` returns the most recent valid capture without starting another.
- `READ?` is equivalent to initiate followed by fetch.
- Any configuration change invalidates the previous capture and stops streaming.
- Status is `0` for idle/no result, `1` for a valid result, and `2` while busy.

`AUTO` starts without waiting. `LEVEL` waits for the trigger GPIO to equal the
selected level. `EDGE` first waits for the opposite level, then waits for the
selected level. Finite triggered capture has no timeout, so a missing trigger
blocks the cooperative main loop.

## Metadata and payload

`LA:METadata?` returns:

```text
sample_rate_hz,pin_base,pin_count,sample_count,word_count,bits_per_word
```

`FETCH?` and `READ?` return little-endian `uint32_t` words in a SCPI arbitrary
block. Each sample occupies `pin_count` low-to-high bits; sample zero begins at
bit zero. Full decoding rules are in [binary data formats](../data-formats.md).

## Streaming

Streaming uses two internal buffers and supports at most 4,096 samples per
frame. Starting LA streaming stops DSO streaming. USB frames have this shape:

```text
LA:STREAM:FRAME <sequence> <payload_bytes>\n
#<digits><length><binary payload>\n
```

`LA:STREAM:STATus?` returns:

```text
enabled,sequence,overruns
```

When wireless transport is effective, frames use UDP capture framing instead
of the USB text header.

## Example

```text
LA:CONF:PINB 16
LA:CONF:PINC 4
LA:CONF:SAMP 4096
LA:CONF:DIV 150
LA:CONF:TRIG:PIN 16
LA:CONF:TRIG:LEV 1
LA:CONF:TRIG:MODE EDGE
LA:READ?
```

Stop LA activity before using MSO, changing the same GPIOs into outputs, or
starting another module that needs PIO0 SM0 or the same pins.

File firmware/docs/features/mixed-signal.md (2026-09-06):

# Mixed-signal capture

MSO captures digital GPIO samples and one analog ADC channel under one trigger.
The digital path uses the logic-analyser PIO/DMA engine; the analog path uses
the internal ADC/DMA frontend.

The ranges below describe the current RP2350A image. On RP2350B the digital
range can be extended to GPIO47 with the PIO window rules, while ADC0–ADC7 move
to GPIO40–GPIO47. The existing `channel + 26` mapping must not be reused; see
[RP2350B migration](../rp2350b-migration.md).

## Defaults and limits

| Setting | Default | Range |
| --- | --- | --- |
| Digital first GPIO | 16 | 0–29, group must end by GPIO29 |
| Digital channels | 1 | 1–8 |
| Analog channel | 0 / GPIO26 | 0–3 / GPIO26–29 |
| Sample rate | 500,000 samples/s | 1–500,000 |
| Samples | 1,024 | 1–4,096 |
| Trigger pin | 16 | 0–29 |
| Trigger level | High | Low or high |
| Trigger mode | `EDGE` | `EDGE` or `LEVEL` |
| Trigger timeout | 1 second | Fixed in the current implementation |

## Commands

- `MSO:CONFigure:DIGital:PINBase <gpio>` and query form
- `MSO:CONFigure:DIGital:PINCount <count>` and query form
- `MSO:CONFigure:ANALog:CHANnel <0..3>` and query form
- `MSO:CONFigure:SAMPles <count>` and query form
- `MSO:CONFigure:RATE <rate>` and query form
- `MSO:CONFigure:TRIGger:PIN <gpio>` and query form
- `MSO:CONFigure:TRIGger:LEVel <bool>` and query form
- `MSO:CONFigure:TRIGger:MODE <EDGE|LEVEL>` and query form
- `MSO:INITiate`
- `MSO:FETCh:DIGital?`, `MSO:FETCh:ANALog?`
- `MSO:READ:DIGital?`, `MSO:READ:ANALog?`
- `MSO:STATus?`, `MSO:METadata?`, `MSO:WIFI:READ?`

## Capture lifecycle

Call `MSO:INITiate` once, then fetch both halves. Each `MSO:READ:*?` starts a
new complete mixed-signal capture before returning only the requested half, so
calling both read queries produces two different captures. Use `INITiate` plus
the two `FETCh` queries when alignment matters.

Status is `0` idle, `1` ready, and `2` busy.

## Synchronization model

Both engines are armed before trigger wait. After the digital trigger is seen,
the firmware starts ADC capture and then PIO capture. Metadata currently reports
both start offsets as zero; these fields are placeholders and do not represent a
measured skew or guaranteed simultaneous first sample.

`MSO:METadata?` returns:

```text
sample_rate_hz,sample_count,digital_pin_base,digital_pin_count,
digital_word_count,digital_bits_per_word,analog_channel,analog_gpio,
digital_start_offset_ns,analog_start_offset_ns
```

The actual response is one comma-separated line; it is wrapped above only for
readability.

## Wi-Fi behavior

`MSO:WIFI:READ?` starts one capture and sends two wireless capture sequences
with the same sequence number: instrument ID `3` for digital data and `4` for
analog data. The SCPI response is the sequence number.

## Example

```text
MSO:CONF:DIG:PINB 16
MSO:CONF:DIG:PINC 2
MSO:CONF:ANAL:CHAN 0
MSO:CONF:RATE 250000
MSO:CONF:SAMP 1024
MSO:CONF:TRIG:PIN 16
MSO:CONF:TRIG:LEV 1
MSO:CONF:TRIG:MODE EDGE
MSO:INIT
MSO:META?
MSO:FETC:DIG?
MSO:FETC:ANAL?
```

Stop LA/DSO streaming before MSO capture and avoid overlap between digital
input pins and other peripheral/output functions.

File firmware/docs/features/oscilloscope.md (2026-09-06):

# Oscilloscope

The DSO captures one RP2350 internal ADC input at a time. The ADC FIFO is paced
by its clock divider and drained into a `uint16_t` buffer with DMA.

The channel/GPIO values below are for the current RP2350A target. RP2350B places
ADC0–ADC7 on GPIO40–GPIO47, so its port requires a different backend mapping;
see [RP2350B migration](../rp2350b-migration.md).

## Defaults and limits

| Setting | Default | Range |
| --- | --- | --- |
| ADC channel | 0 | 0–3 |
| GPIO | 26 | 26–29, derived from channel |
| Sample rate | 100,000 samples/s | 1–500,000 samples/s |
| Samples | 1,024 | 1–4,096 |
| Trigger mode | `OFF` | `OFF`, `LEVEL`, `EDGE` |
| Trigger level | 2,048 | 0–4,095 raw ADC counts |
| Trigger slope | `RISE` | `RISE`/`RISING`, `FALL`/`FALLING` |

The data is raw 12-bit ADC output stored in the low bits of little-endian
`uint16_t` values. Voltage conversion depends on the board analog reference and
front-end circuitry; the firmware does not currently apply calibration.

## Commands

- `DSO:CONFigure:CHANnel <0..3>` and query form
- `DSO:CONFigure:GPIO?`
- `DSO:CONFigure:SAMPles <1..4096>` and query form
- `DSO:CONFigure:RATE <1..500000>` and query form
- `DSO:CONFigure:TRIGger:LEVel <0..4095>` and query form
- `DSO:CONFigure:TRIGger:MODE <OFF|LEVEL|EDGE>` and query form
- `DSO:CONFigure:TRIGger:SLOPe <RISE|FALL>` and query form
- `DSO:INITiate`, `DSO:FETCh[:DATa]?`, `DSO:READ?`, `DSO:STATus?`
- `DSO:STREAM:STARt`, `DSO:STREAM:STOP`, `DSO:STREAM:STATus?`
- `DSO:WIFI:READ?`

## Trigger behavior

`OFF` begins the DMA capture immediately. `LEVEL` repeatedly samples until the
value is at/above the threshold for rising mode or at/below it for falling mode.
`EDGE` waits for the signal to be on the opposite side, then cross to the chosen
side.

Finite `INITiate`/`READ?` uses no trigger timeout. A missing trigger blocks the
main loop. Streaming uses a 10 ms timeout per attempted frame; a timeout
increments the overrun count and streaming remains enabled for later attempts.

## Capture and streaming

`INITiate` stores a capture, `FETCh?` returns it, and `READ?` combines both.
Status values are `0` idle, `1` capture ready, and `2` busy/streaming.

Starting DSO streaming stops LA streaming. USB stream frames use the prefix
`DSO:STREAM:FRAME`; wireless frames use instrument ID `2`.

## Example

```text
DSO:CONF:CHAN 0
DSO:CONF:GPIO?
DSO:CONF:RATE 250000
DSO:CONF:SAMP 2048
DSO:CONF:TRIG:LEV 2048
DSO:CONF:TRIG:MODE EDGE
DSO:CONF:TRIG:SLOP RISE
DSO:READ?
```

Stop DSO streaming before using mixed-signal capture because both use the one
internal ADC/DMA backend.

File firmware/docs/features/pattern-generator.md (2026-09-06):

# Digital pattern generator

The pattern generator uses PIO0 state machine 1 and DMA to output packed digital
samples on 1–8 consecutive GPIO pins.

The GPIO ranges below are current RP2350A firmware limits. RP2350B can use an
output bank above GPIO31 only after the range checks are changed and PIO0 is
configured for its GPIO16–47 window. That window is shared with the logic
analyser state machine; see [RP2350B migration](../rp2350b-migration.md).

## Defaults and limits

| Setting | Default | Range |
| --- | --- | --- |
| First GPIO | 16 | 0–29, group must end by GPIO29 |
| Output count | 1 | 1–8 |
| Sample rate | 2,000 samples/s | Requested 1–75,000,000; also constrained by PIO divider |
| Mode | `ONCE` | `ONCE` or `LOOP` |
| Pattern storage | Empty | Up to 16,384 `uint32_t` words / 64 KiB |

The PIO clock divider must remain in `[1, 65536]`. The lowest and highest
achievable rates therefore depend on `clk_sys`; a request inside the application
range can still be rejected by the platform.

## Commands

- `PG:CONFigure:PINS <first_gpio>,<count>` and query form
- `PG:CONFigure:RATE <samples_per_second>` and query form
- `PG:CONFigure:MODE <ONCE|LOOP>` and query form
- `PG:DATA <arbitrary_block>`
- `PG:STARt`, `PG:STOP`, `PG:STATus?`, `PG:UNDerrun?`

Pin, rate, mode, and pattern data cannot be changed while output is running.
`START` fails until a non-empty pattern has been uploaded.

## Packing

`PG:DATA` must contain a whole number of little-endian `uint32_t` words. A word
contains `floor(32 / pin_count)` samples. Within each word:

- sample zero occupies the least-significant `pin_count` bits;
- the bit at offset zero drives `pin_base`;
- successive samples occupy successive groups of `pin_count` bits;
- unused high bits are ignored when 32 is not divisible by the pin count.

The pattern-generator packing is the inverse of the LA unpacking convention.

## Effective upload-size limit

The pattern buffer accepts 64 KiB, but the current SCPI parser has a 1,024-byte
input buffer. A single `PG:DATA` command, including its header, must fit in that
buffer. There is no chunked append command yet, so the current host-visible
limit is roughly 1 KiB rather than the full backing buffer.

## Modes and status

`ONCE` stops after the last word. `LOOP` uses a control DMA channel to restart
the data DMA channel. `PG:STATus?` returns:

```text
running,rate_hz,pin_count,pattern_words
```

`PG:UNDerrun?` returns the observed PIO TX stall count while loop mode is active.

## Python upload example

```python
import struct
import serial

samples = [0, 1, 2, 3] * 8  # two output bits per sample
word = sum((value & 0x3) << (index * 2) for index, value in enumerate(samples[:16]))
payload = struct.pack("<II", word, word)
block = b"#" + str(len(str(len(payload)))).encode() + str(len(payload)).encode() + payload

with serial.Serial("/dev/ttyACM0", 115200, timeout=1) as port:
    port.write(b"PG:CONF:PINS 16,2\n")
    port.write(b"PG:CONF:RATE 10000\n")
    port.write(b"PG:CONF:MODE LOOP\n")
    port.write(b"PG:DATA " + block + b"\n")
    port.write(b"PG:START\n")
```

Stop the output before reconnecting those pins to an external driver or using
them as LA/MSO inputs.

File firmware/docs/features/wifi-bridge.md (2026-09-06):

# ESP32-C3 Wi-Fi bridge

The optional ESP32-C3 companion turns the RP2350's local USB instrument into a
network instrument. The Pico remains responsible for SCPI parsing and all
measurement functions; the ESP provides Wi-Fi provisioning, TCP/UDP sockets,
mDNS, and a framed SPI link.

```text
SCPI client -- TCP 5006 -- ESP32-C3 == SPI == RP2350 -- instruments
UDP receiver <- UDP 5005 -/              \\-- USB CDC remains available
```

## Wiring

| Signal | RP2350 Pico GPIO | ESP32-C3 default GPIO | Direction relative to Pico |
| --- | ---: | ---: | --- |
| SCLK | 2 | 4 | output |
| MOSI / Pico TX | 3 | 5 | output |
| MISO / Pico RX | 4 | 6 | input |
| CS | 5 | 7 | output |
| READY | 6 | 10 | input |
| GND | GND | GND | common reference |

Both boards use 3.3 V logic. Connect grounds. Do not apply 5 V to signal pins.
The Pico link is SPI0, mode 0, 1 MHz. GPIO4/5 conflicts with the UART gateway,
and GPIO6 conflicts with I2C1.

## Build and flash the ESP

Use an ESP-IDF shell whose target supports the ESP32-C3:

```bash
cd esp_firmware
idf.py set-target esp32c3
idf.py menuconfig       # optional: LibreLab ESP SPI bridge
idf.py build
idf.py -p /dev/ttyUSB0 flash monitor
```

Build and flash the RP2350 image separately as described in
[building](../building.md). The bridge feature is compiled into the normal Pico
target; no Pico CMake switch is required.

## First-time provisioning

Credentials are stored in ESP NVS. With no usable saved network, or after ten
failed station attempts/approximately 15 seconds, the ESP starts a temporary
SoftAP named `LibreLab-Pico-XXXX`. The suffix is derived from the device identity.

1. Connect a phone or computer to that AP.
2. Use the default WPA2 password `librelab-pico`, unless changed in menuconfig.
3. Open `http://192.168.4.1`.
4. Enter the destination Wi-Fi SSID and password.
5. Allow the ESP to restart/connect, then watch its serial monitor for the IP.

The provisioning page is plain HTTP inside the password-protected setup AP.
Stored credentials persist in NVS. Use `idf.py erase-flash` only when you
intentionally want to remove them and all other ESP flash state.

## Enabling wireless operation on the Pico

The Pico boots in `USB` transport mode and does not poll the ESP in that mode.
Bootstrap each Pico boot over USB:

```text
COMM:TRAN AUTO
COMM:TRAN?
COMM:WIFI:STAT?
```

`AUTO` uses Wi-Fi when READY is asserted and otherwise emits stream data over
USB. `WIFI` forces the wireless path. Forced Wi-Fi reports the mode as effective
even if the companion is absent, so use the sent/dropped/timeout counters and
ESP logs when diagnosing the link.

## Network endpoints

| Endpoint | Default | Purpose |
| --- | --- | --- |
| TCP | ESP address, port 5006 | Raw SCPI request/response connection |
| UDP capture | destination port 5005 | Fixed 512-byte bridge frames, up to two per datagram |
| UDP registration | ESP address, port 5006 | Register receiver address with `LIBRELAB_UDP_REGISTER` |
| mDNS | `librelab-pico.local` | Hostname |
| DNS-SD | `_librelab._tcp` | TCP service advertisement |

One straightforward TCP session is:

```bash
printf '*IDN?\n' | nc librelab-pico.local 5006
```

For a wireless one-shot capture, keep the TCP connection open, register the UDP
receiver, then issue `LA:WIFI:READ?`, `DSO:WIFI:READ?`, or `MSO:WIFI:READ?`.
The SCPI response is the capture sequence; metadata and capture data arrive over
UDP. Ordinary `LA:READ?` and `DSO:READ?` return their binary blocks on the SCPI
connection instead.

Continuous `LA:STREAM:START` or `DSO:STREAM:START` uses UDP capture frames when
wireless is effective. See [data formats](../data-formats.md) for reassembly.

## ESP configuration options

Run `idf.py menuconfig` and open **LibreLab ESP SPI bridge**.

| Option | Default |
| --- | --- |
| Provisioning AP password | `librelab-pico` |
| Initial UDP destination | `255.255.255.255` |
| UDP capture destination port | 5005 |
| TCP SCPI / UDP registration port | 5006 |
| SCLK, MOSI, MISO, CS, READY GPIO | 4, 5, 6, 7, 10 |
| Serial statistics interval | 1,000 ms |

Changing ESP pins also requires wiring them to the fixed Pico pins, unless the
Pico platform source is changed and rebuilt.

## Runtime architecture

The ESP queues validated SPI frames between its SPI-slave task and network
tasks. Capture frames are sent by UDP. TCP input is wrapped as type-3 SCPI frames
and returned during a later full-duplex Pico SPI exchange; Pico responses travel
back as the same frame type. READY signals that the ESP has a transaction queued.

The Pico link uses fixed frames with magic, type, sequence, payload length, and
an 8-bit header checksum. Captures add a versioned inner header and separate
metadata/data chunks. This separation lets a receiver interpret a capture
without relying on the preceding SCPI conversation.

## Diagnostics and limitations

- `COMM:WIFI:STATus?` returns `effective,sent,dropped,timeouts` from the Pico.
- The ESP serial monitor periodically reports received frames, queued frames,
  validation failures, queue drops, SCPI frames, and the last sequence.
- `esp_firmware/bridge_receiver.py` is a low-level link diagnostic. Its payload
  check expects deterministic synthetic pattern traffic; it is not a complete
  decoder for the current `LBLB` capture format.
- UDP can lose, duplicate, or reorder frames. Detect this with outer sequence
  numbers and inner capture/chunk fields.
- TCP SCPI and UDP capture traffic have no authentication or encryption. Do not
  expose ports 5005/5006 to an untrusted network or the public Internet.
- Only one pending Pico-side SCPI payload is buffered, with a maximum of 500
  bytes per bridge frame. Keep commands concise and serialize client access.

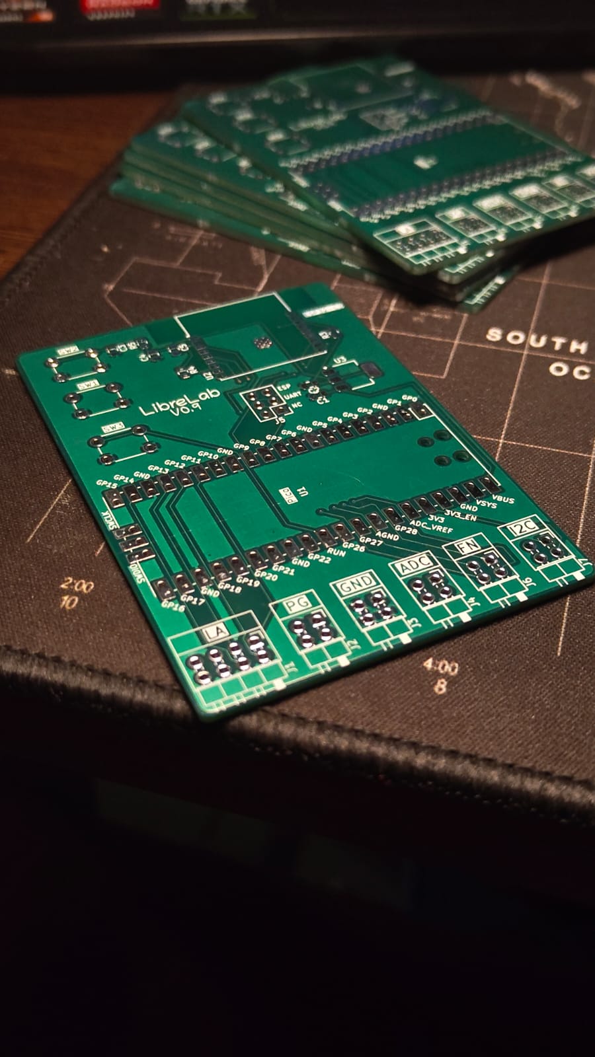
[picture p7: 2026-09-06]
docs/assets/librelab-v0.9-pcb-stack.jpeg

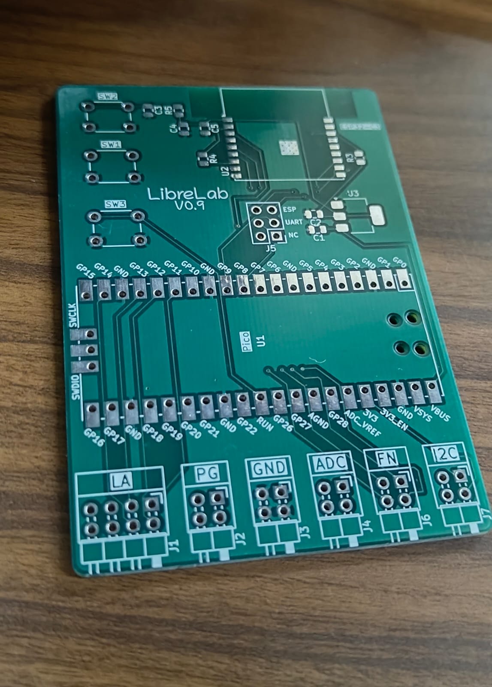
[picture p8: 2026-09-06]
docs/assets/librelab-v0.9-pcb-top.jpeg

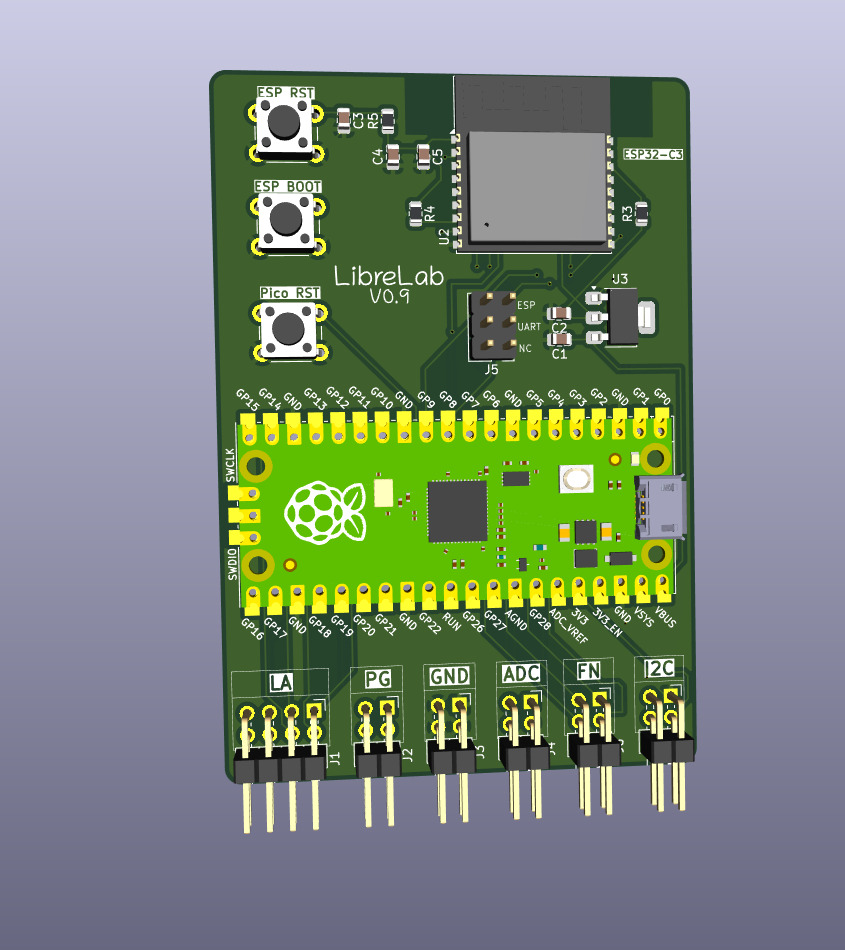
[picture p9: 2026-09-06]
docs/assets/librelab-v0.9-render.jpeg

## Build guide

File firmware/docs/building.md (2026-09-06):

# Building and flashing

The repository contains two independent embedded projects:

- The root CMake project currently builds `librelab_pico` for Pico 2/RP2350A.
- `esp_firmware/` is an ESP-IDF project for ESP32-C3.

## RP2350 firmware

The commands in this section build the current RP2350A target. `PICO_BOARD=pico2`
selects the Pico 2 board definition, including `PICO_RP2350A=1`; it is not a
valid final board definition for a custom RP2350B PCB.

### Toolchain

The build requires CMake 3.13+, the Arm GNU embedded compiler, and a Pico SDK
checkout with submodules. Pico SDK 2.1.0 is known to build this snapshot.

Set the SDK path either in the environment:

```bash
export PICO_SDK_PATH=/opt/pico-sdk
```

or on the CMake command line:

```bash
cmake -S . -B build-pico2 \
  -DPICO_BOARD=pico2 \
  -DPICO_SDK_PATH=/opt/pico-sdk
```

### Configure and build

Ninja:

```bash
cmake -S . -B build-pico2 -G Ninja -DPICO_BOARD=pico2
cmake --build build-pico2 --target librelab_pico
```

Unix Makefiles:

```bash
cmake -S . -B build-pico2 -DPICO_BOARD=pico2
cmake --build build-pico2 --target librelab_pico -j"$(nproc)"
```

For diagnostic symbols:

```bash
cmake -S . -B build-debug -G Ninja \
  -DPICO_BOARD=pico2 \
  -DCMAKE_BUILD_TYPE=Debug
cmake --build build-debug --target librelab_pico
```

### Outputs

CMake places the main outputs at the top of the selected build directory:

| File | Purpose |
| --- | --- |
| `librelab_pico.elf` | Debugger and symbol-rich executable |
| `librelab_pico.uf2` | BOOTSEL drag-and-drop image |
| `librelab_pico.bin` | Raw binary image |
| `librelab_pico.hex` | Intel HEX image |
| `librelab_pico.dis` | Disassembly when generated by Pico SDK tools |
| `librelab_pico.elf.map` | Linker map |

### Flashing

BOOTSEL is the simplest method. Copy the UF2 to the mass-storage volume exposed
while BOOTSEL is held.

With `picotool`:

```bash
picotool load -f build-pico2/librelab_pico.uf2
picotool reboot
```

For SWD, use the `ELF` with OpenOCD, probe-rs, or your IDE. Probe and target
configuration varies, so follow the probe vendor’s RP2350 instructions.

### Clean rebuild

Build directories are disposable:

```bash
cmake --build build-pico2 --target clean
```

If CMake cached an incorrect SDK or board, create a new build directory rather
than editing the cache manually.

### Future RP2350B target

The future PCB needs its own Pico SDK board header and a separate build
directory. The board definition must select platform `rp2350`, set
`PICO_RP2350A` to `0` (the SDK's current spelling for the B package), and define
the actual flash, LED, and other board properties. A future configure command
will have this shape once `boards/librelab_rp2350b.h` exists:

```bash
cmake -S . -B build-rp2350b -G Ninja \
  -DPICO_BOARD=librelab_rp2350b \
  -DPICO_BOARD_HEADER_DIRS="$PWD/boards"
```

Creating that board header alone is insufficient: the ADC mapping, GPIO range
checks, fixed peripheral mappings, and PIO GPIO base also require the changes
listed in [RP2350B migration](rp2350b-migration.md). Until those changes and a
hardware test pass are complete, RP2350B is a planned target rather than a
supported build.

## ESP32-C3 bridge firmware

### Toolchain

Use ESP-IDF 5.1.x. The component lock records ESP-IDF 5.1.1 and mDNS component
1.2.5 for the verified snapshot.

Load ESP-IDF into the shell, then select the target:

```bash
. /path/to/esp-idf/export.sh
cd esp_firmware
idf.py set-target esp32c3
```

### Configure

Defaults live in `esp_firmware/sdkconfig.defaults`. Project-specific options are
under the `LibreLab ESP SPI bridge` menu:

```bash
idf.py menuconfig
```

The configurable values are the provisioning AP password, initial UDP
destination/ports, Pico-link SPI pins, READY pin, and serial statistics interval.
The provisioning password must contain at least eight characters.

### Build and flash

```bash
idf.py build
idf.py -p /dev/ttyACM1 flash
idf.py -p /dev/ttyACM1 monitor
```

Combined flash and monitor:

```bash
idf.py -p /dev/ttyACM1 flash monitor
```

Leave the monitor with `Ctrl-]`.

### Erase saved Wi-Fi credentials

Wi-Fi credentials are stored in NVS. To force provisioning again, erase flash
and reflash:

```bash
idf.py -p /dev/ttyACM1 erase-flash
idf.py -p /dev/ttyACM1 flash monitor
```

This destroys all ESP flash contents, including saved credentials.

## Build reproducibility notes

- Keep generated `build*`, `sdkconfig`, managed-component, and compiler output
  out of source control unless a project policy explicitly says otherwise.
- `dependencies.lock` pins the ESP component resolution.
- The root build uses the Pico SDK supplied by the developer; pin that SDK in
  the parent project or CI environment for reproducible binaries.

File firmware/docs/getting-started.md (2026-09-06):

# Getting started

This guide builds the current RP2350A firmware, flashes a Pico 2, opens the USB
CDC interface, and performs a simple digital capture.

## 1. Install prerequisites

You need:

- Git
- CMake 3.13+
- Ninja or Make
- Python 3
- Arm GNU embedded toolchain
- Raspberry Pi Pico SDK 2.1+

On Debian/Ubuntu, the compiler and common build tools can be installed with:

```bash
sudo apt update
sudo apt install cmake ninja-build gcc-arm-none-eabi libnewlib-arm-none-eabi python3-pip
```

Obtain the Pico SDK with its submodules and export its path:

```bash
git clone --recurse-submodules https://github.com/raspberrypi/pico-sdk.git
export PICO_SDK_PATH="$PWD/pico-sdk"
```

## 2. Build the RP2350 image

From the firmware root:

```bash
cmake -S . -B build-pico2 -G Ninja -DPICO_BOARD=pico2
cmake --build build-pico2 --target librelab_pico
```

If `picotool` is not installed, Pico SDK may download and build it during the
first configure. See [building and flashing](building.md) for offline and custom
SDK setups.

## 3. Flash the board

For BOOTSEL flashing:

1. Disconnect the Pico.
2. Hold BOOTSEL while reconnecting USB.
3. Copy `build-pico2/librelab_pico.uf2` to the `RPI-RP2` drive.
4. Wait for the board to reboot.

With `picotool` and a board already in BOOTSEL mode:

```bash
picotool load -f build-pico2/librelab_pico.uf2
picotool reboot
```

## 4. Find the command port

Linux usually exposes the device as `/dev/ttyACM0`. Useful checks are:

```bash
ls -l /dev/ttyACM*
python3 -m serial.tools.list_ports -v
```

If `serial.tools` is unavailable:

```bash
python3 -m pip install pyserial
```

Open a raw terminal:

```bash
python3 -m serial.tools.miniterm /dev/ttyACM0 115200 --raw
```

Send `*IDN?` followed by Enter. The response should identify
`FOSSASIA,LibreLab Pico`.

## 5. Make a first logic capture

Connect a 3.3 V digital signal to GPIO16 and share ground with the signal
source. Never apply 5 V to an RP2350 GPIO.

Configure one channel and 256 samples:

```text
LA:CONF:PINB 16
LA:CONF:PINC 1
LA:CONF:SAMP 256
LA:CONF:DIV 150
LA:CONF:TRIG:MODE AUTO
LA:META?
LA:READ?
```

At a 150 MHz system clock, divider 150 gives approximately 1 MS/s. Always use
`LA:CONF:RATE?` to read the actual rate rather than assuming a system clock.

`LA:READ?` returns a SCPI definite-length binary block. A terminal will display
the header and binary payload poorly; production clients should parse the block
as described in [binary data formats](data-formats.md).

## 6. Exercise a text-only feature

The built-in square-wave generator is easier to inspect in a terminal:

```text
TEST:SQU:CONF 15,1000
TEST:SQU?
TEST:SQU:PIN?
TEST:SQU:FREQ?
TEST:SQU 0
```

The output is a 1 kHz, approximately 50% duty square wave on GPIO15 until it is
disabled.

## 7. Next steps

- Review [hardware resources](hardware.md) before wiring multiple features.
- Use the [complete command reference](scpi-reference.md) for automation.
- Follow [Wi-Fi bridge](features/wifi-bridge.md) to add an ESP32-C3.
- Follow the feature-specific guides for limits, data layouts, and examples.

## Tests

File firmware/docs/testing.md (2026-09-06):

# Testing and verification

The repository has three validation surfaces: the current RP2350A cross-build,
the ESP-IDF build, and a standalone host test for sigrok packing.

## RP2350 build check

From the firmware root:

```bash
cmake -S . -B build-pico2 -G Ninja \
  -DPICO_BOARD=pico2 \
  -DPICO_SDK_PATH=/path/to/pico-sdk
cmake --build build-pico2 --target librelab_pico
```

A successful build must produce `build-pico2/librelab_pico.elf` and
`build-pico2/librelab_pico.uf2`. Treat compiler warnings as defects when making
new changes even though the root target does not globally enable `-Werror`.

## ESP bridge build check

From an ESP-IDF 5.1.x shell:

```bash
cd esp_firmware
idf.py set-target esp32c3
idf.py build
```

When editing bridge protocol structures, build both MCUs: constants and frame
layouts are duplicated on the Pico and ESP sides.

## Standalone sigrok packing test

This host-native test is runnable without hardware:

```bash
make -C tools/sigrok/librelab-pico test
make -C tools/sigrok/librelab-pico clean
```

It compiles `test_unpack.c` and validates the conversion from packed capture
words to one logic byte per sample. It does not test serial I/O or the complete
libsigrok integration.

## Python syntax checks

The bridge diagnostic utility can be syntax-checked without opening a socket:

```bash
python3 -c 'compile(open("esp_firmware/bridge_receiver.py", "rb").read(), \
  "esp_firmware/bridge_receiver.py", "exec")'
```

## Hardware smoke test

After flashing a new build, verify at least the following:

1. USB enumerates as a CDC device and `*IDN?` returns the documented identity.
2. `*CLS` followed by `SYST:ERR:COUN?` returns zero.
3. Enable `TEST:SQU ON`, wire GPIO15 to an LA input, and confirm frequency and
   duty cycle with `LA:READ?` in `AUTO` mode.
4. Loop GPIO15 to ADC0 through a safe 3.3 V-compatible connection and confirm a
   DSO capture changes with the signal. Never exceed the ADC input range.
5. Exercise only the bus gateway whose pins are free; verify open, transfer,
   error reporting, and close.
6. If using the ESP, provision Wi-Fi, select `COMM:TRAN AUTO`, query over TCP,
   register a UDP receiver, and verify capture sequences/chunks without loss.
7. Run LA and DSO streams separately and verify that starting one stops the
   other.

For triggered tests, first prove the trigger source is present. LA and finite
DSO trigger waits can block the command loop indefinitely.

## Documentation consistency checks

When command registration changes, update
`docs/scpi-reference.md`, the relevant feature page, and any data-format page in
the same change. A useful manual audit is:

```bash
sed -n '/g_SCPI_COMMANDS\[\]/,/SCPI_CMD_LIST_END/p' \
  src/application/protocol/common.c
```

Also check Markdown links before release:

```bash
rg -n '\]\([^)]*\.md' README.md docs
```

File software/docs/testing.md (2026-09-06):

# Testing

The app is testable without LibreLab hardware. The simulator is not just placeholder UI; it implements the same `LibreLabApi` shape that the hardware backend will implement.

## Unit And Component Tests

Run:

```bash
npm test
```

Coverage today includes:

- deterministic capture generation in `src/shared/mockCapture.test.ts`;
- formatter behavior in `src/renderer/src/lib/format.test.ts`;
- a full renderer workflow in `src/renderer/src/App.test.tsx`.

The renderer workflow test connects to a fake simulator, captures data, switches panels, toggles decoder visibility, and changes instrument mode. Canvas and `ResizeObserver` are shimmed in `src/renderer/src/test/setup.ts` so jsdom can execute the waveform component.

## GUI Smoke Test

Run:

```bash
npm run test:e2e
```

On a fresh machine, install the Playwright browser once:

```bash
npx playwright install chromium
```

The smoke test builds the Electron app, starts a Vite renderer server, opens it with Playwright Chromium, connects to the built-in simulator, captures data, verifies the waveform canvas exists, opens analyzers, and sends a bus-console message.

## Documentation Screenshots

Run:

```bash
npm run docs:screenshots
```

The script captures the simulator workspace, analyzer panel, and bus console into `docs/assets/`. It starts the renderer dev server if one is not already reachable at `http://127.0.0.1:5174/`.

## Hardware Testing Plan

When the native device engine lands, keep the current simulator tests and add hardware-facing tests in layers:

- contract tests against recorded capture fixtures;
- device discovery tests behind an opt-in environment variable;
- streaming tests with short captures and clear timeouts;
- decoder fixture tests that compare libsigrokdecode annotations against expected spans.

Do not make ordinary CI require a physical board.

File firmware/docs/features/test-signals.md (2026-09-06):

# Built-in test signals

Two PWM-backed outputs provide convenient signals for capture and wiring tests.
Despite the command name, `TEST:ANALog` is not a DAC: it is a digital PWM output
whose average voltage depends on duty cycle and any external filtering.

## Square output

Defaults are GPIO15, 1 kHz, approximately 50% duty.

- `TEST:SQUare <bool>` enables defaults or disables the output.
- `TEST:SQUare?` reports enabled state.
- `TEST:SQUare:CONFigure <gpio>,<frequency_hz>` configures and immediately starts.
- `TEST:SQUare:PIN?` and `TEST:SQUare:FREQuency?` report active settings.

## PWM “analog” output

Defaults are GPIO13, 1 kHz, 500 permille (50% duty).

- `TEST:ANALog <bool>` enables defaults or disables the output.
- `TEST:ANALog?` reports enabled state.
- `TEST:ANALog:CONFigure <gpio>,<frequency_hz>,<duty_permille>` configures and starts.
- `TEST:ANALog:PIN?`, `FREQuency?`, and `DUTY?` report settings.

The current RP2350A build limits GPIO to 0–29. Frequency must be nonzero and
achievable with an RP2350 PWM divider in `[1,255]`, and duty is 0–1000
permille.

RP2350B adds GPIO30–47 and PWM slices 8–11, but the firmware range checks must
be made package-aware before those pins can be selected. Distinct GPIOs can
still conflict when they are outputs of the same PWM slice.

The two outputs cannot use GPIOs belonging to the same PWM slice at the same
time. Configuration fails if the requested output conflicts with the other
active test signal’s PWM slice.

## Loopback examples

Square output into the LA:

```text
TEST:SQU:CONF 15,1000
LA:CONF:PINB 14
LA:CONF:PINC 2
LA:CONF:SAMP 1024
LA:CONF:TRIG:PIN 15
LA:CONF:TRIG:MODE EDGE
LA:READ?
TEST:SQU 0
```

Physically jumper GPIO15 to one selected LA input if the capture group does not
already include it.

PWM output into DSO:

```text
TEST:ANAL:CONF 13,1000,250
DSO:CONF:CHAN 0
DSO:CONF:TRIG:MODE OFF
DSO:READ?
TEST:ANAL 0
```

Physically connect GPIO13 to GPIO26 through appropriate protection. GPIO13 is
also the generic SPI gateway chip-select, so do not use both defaults together.

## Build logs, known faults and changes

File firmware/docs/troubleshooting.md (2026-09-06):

# Troubleshooting

## CMake cannot find the Pico SDK

Set `PICO_SDK_PATH` to a complete Pico SDK checkout before the first configure,
or pass `-DPICO_SDK_PATH=/path/to/pico-sdk`. If a build directory cached the
wrong path or board, configure a new build directory.

```bash
cmake -S . -B build-pico2 -G Ninja \
  -DPICO_BOARD=pico2 \
  -DPICO_SDK_PATH=/path/to/pico-sdk
```

Use Pico SDK 2.1 or newer for the current RP2350A/Pico 2 target and ensure SDK
submodules are initialized.

## The UF2 or expected artifact is missing

Build the explicit target and inspect the top of the build directory:

```bash
cmake --build build-pico2 --target librelab_pico
find build-pico2 -maxdepth 1 -name 'librelab_pico.*' -print
```

The active target is `librelab_pico`, not the older artifact name used by the
existing workflow.

## No USB serial device appears

- Confirm that the flashed image is `librelab_pico.uf2` for Pico 2/RP2350A.
- Try a known data-capable USB cable and another port.
- On Linux, inspect `dmesg` and `/dev/ttyACM*`; add your user to the distribution's
  serial-device group if access is denied.
- Close other terminal, IDE, ModemManager, or sigrok sessions that hold the CDC
  port.
- The USB descriptor uses VID `0xCAFE`, PID `0x4010`, product `LibreLab Pico`,
  and interface name `SCPI CDC`.

## The device does not answer a command

Send a newline-terminated command. USB CDC ignores the terminal baud setting,
but raw mode avoids unwanted local echo and line conversion.

```bash
python3 -m serial.tools.miniterm /dev/ttyACM0 115200 --raw
```

Try `*IDN?`, then `*CLS` and `SYST:ERR?`. If a triggered LA or finite DSO command
was sent without a reachable trigger, the synchronous command handler may be
waiting indefinitely; provide the trigger or reset the board.

## Binary output looks like garbage

`LA:READ?`, `DSO:READ?`, MSO fetches, and bus reads return SCPI arbitrary blocks,
not printable text. Read the `#` header and exact payload length in a binary-safe
program. Do not use `readline()` for the payload because sample bytes can contain
LF. See [data formats](data-formats.md).

## Capture length or pattern upload is rejected

- LA finite captures allow 1–65,536 samples; LA streaming allows at most 4,096.
- DSO and MSO allow 1–4,096 samples.
- Gateway transfers allow at most 512 bytes.
- Although the pattern buffer holds 64 KiB, `PG:DATA` shares a 1,024-byte SCPI
  input buffer. There is currently no chunked pattern-upload command.

Read `SYST:ERR?` immediately after the rejected command to distinguish an
illegal parameter from an execution failure.

## A signal or peripheral stops when another feature starts

Check [hardware resources](hardware.md). Several defaults overlap and the
firmware has no central pin arbiter. Common collisions are:

- UART1 and the Wi-Fi bridge on GPIO4/5;
- I2C0 and log UART0 on GPIO0/1;
- I2C1 and Wi-Fi READY on GPIO6;
- SPI CS and PWM test output on GPIO13;
- LA, MSO digital, and pattern output beginning at GPIO16;
- PWM outputs that use the same PWM slice even when their GPIO numbers differ.

Stop one feature and move configurable capture/test pins before enabling the
other. Gateway and Wi-Fi pins are fixed in the current Pico build.

## SPI gateway OPEN always fails

This is a known firmware integration defect. The SCPI layer permits bus `1`,
while the system layer exposes logical bus `0` mapped to hardware SPI1. The
commands are compiled but the gateway cannot currently be opened. This is not a
wiring or client syntax problem.

## I2C devices are absent from SCAN

- Confirm the correct bus/pins: bus 0 is GPIO0/1, bus 1 is GPIO6/7.
- Make sure both devices share ground and use 3.3 V-compatible levels.
- Internal pull-ups are enabled but may be too weak for the bus capacitance;
  use suitable external pull-ups when required.
- Lower the configured rate and verify the target uses a non-reserved 7-bit
  address between `0x08` and `0x77`.
- Disconnect UART logging from GPIO0/1 when using I2C0, and disconnect ESP READY
  from GPIO6 when using I2C1.

## ESP provisioning AP does not appear

Watch the ESP serial monitor. It first tries saved credentials up to ten times
and waits roughly 15 seconds before entering provisioning. If stale credentials
must be removed, `idf.py erase-flash` followed by a reflash is effective but
destructive to all ESP flash state.

The default AP is `LibreLab-Pico-XXXX`, password `librelab-pico`, and setup page
`http://192.168.4.1`. Menuconfig can change the password.

## TCP SCPI does not reach the Pico

1. Verify the ESP joined Wi-Fi and port 5006 is reachable by IP; mDNS may not
   cross VLANs, so try the numeric address instead of `librelab-pico.local`.
2. Verify shared ground and all five SPI/READY wires.
3. After every Pico reboot, send `COMM:TRAN AUTO` or `COMM:TRAN WIFI` over USB.
   The default `USB` mode does not poll wireless commands.
4. Check `COMM:WIFI:STAT?` counters over USB and the ESP's periodic serial
   statistics.
5. Avoid simultaneous TCP clients; commands share a small queued bridge path.

## UDP captures do not arrive or are incomplete

- Bind a receiver to UDP 5005 and send `LIBRELAB_UDP_REGISTER` to the ESP's UDP
  port 5006 so it learns the receiver address.
- Permit UDP 5005/5006 in the host firewall and keep both endpoints on a network
  that allows the traffic.
- Split datagrams into 512-byte frames; a datagram may contain two frames.
- Validate outer sequence/checksum and inner capture/chunk fields. UDP provides
  no retransmission, so missing chunks make that capture incomplete.
- The bundled `bridge_receiver.py` expects synthetic diagnostic patterns and is
  not a complete current capture decoder.

## Logs interfere with I2C0 or appear missing

Firmware diagnostics use UART0 GPIO0 TX/GPIO1 RX at 115200 8N1, not USB CDC.
Using I2C0 reconfigures the same pins. Choose I2C1 only when its GPIO6 conflict
with the Wi-Fi bridge is also acceptable, or disable/move one subsystem in code.

## The analog test output is not an analog waveform

`TEST:ANALog` is PWM on GPIO13. It is not a DAC and its raw output switches
between logic levels. Add an appropriate low-pass filter if a smoothed voltage
is required, and account for load impedance and ripple.

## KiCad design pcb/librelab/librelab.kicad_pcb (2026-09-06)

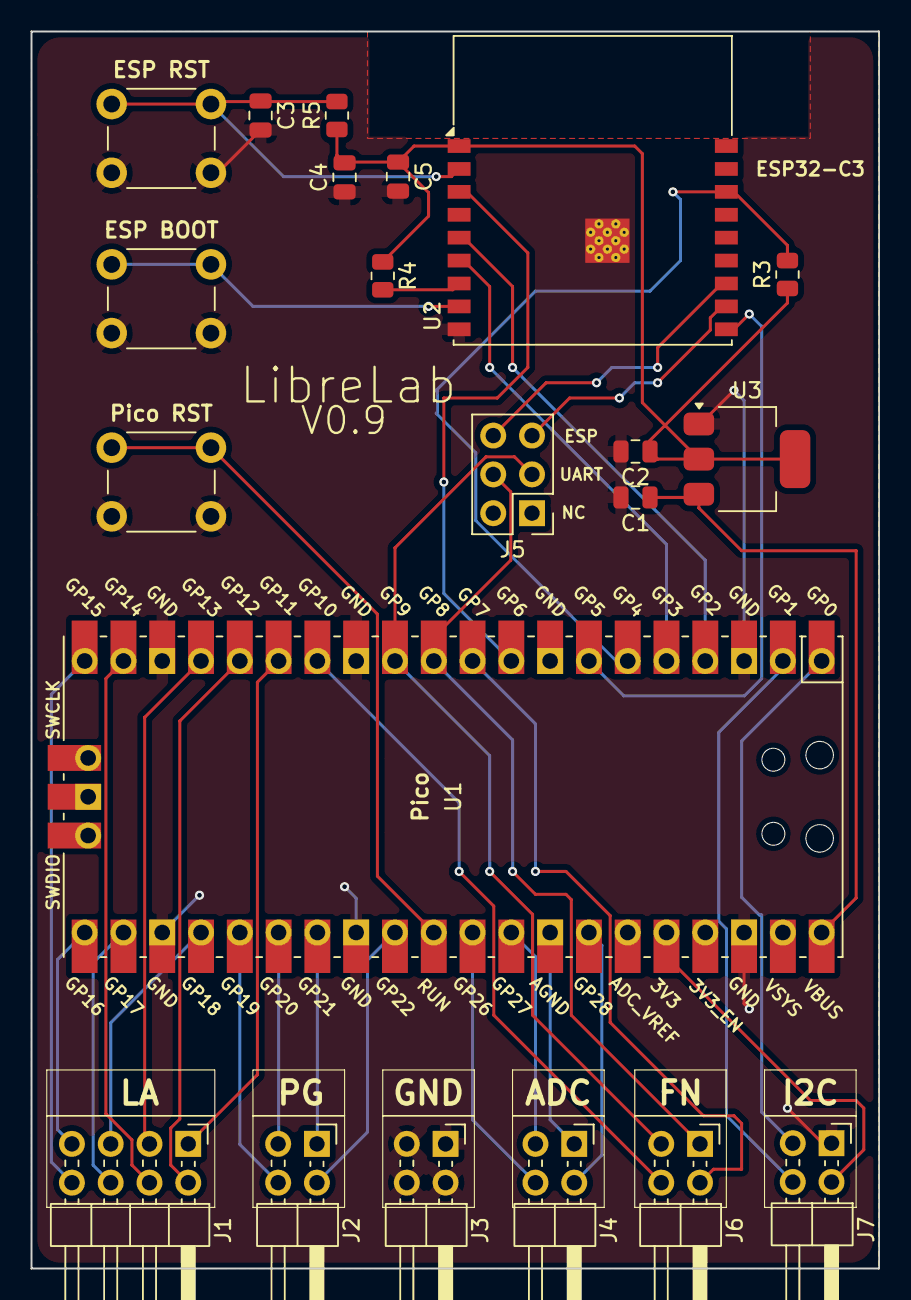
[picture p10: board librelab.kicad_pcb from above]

Board: 2 copper layers, 55.5 x 81.0 mm, 21 parts (0 on the bottom side), 36 nets.

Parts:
C1, C2, C5: 10uF; C_0805_2012Metric
C3: 1uF; C_0805_2012Metric
C4: 100n; C_0805_2012Metric
ESP BOOT: SW_Push; SW_PUSH_6mm_H5mm
ESP RST: SW_Push; SW_PUSH_6mm_H5mm
J1: LA headers; PinHeader_2x04_P2.54mm_Horizontal
J2: PG headers; PinHeader_2x02_P2.54mm_Horizontal
J3: GND headers; PinHeader_2x02_P2.54mm_Horizontal
J4: ADC headers; PinHeader_2x02_P2.54mm_Horizontal
J5: Conn_02x03_Counter_Clockwise; PinHeader_2x03_P2.54mm_Vertical
J6: FN headers; PinHeader_2x02_P2.54mm_Horizontal
J7: I2C headers; PinHeader_2x02_P2.54mm_Horizontal
Pico RST: SW_Push; SW_PUSH_6mm_H5mm
R3, R4, R5: 10k; R_0805_2012Metric
U1: Pico; RPi_Pico_SMD_TH
U2: ESP32-C3-WROOM-02
U3: AMS1117-3.3; SOT-223-3_TabPin2

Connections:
+3V3: C2.1, C4.2, C5.1, J7.2, R3.1, R4.1, R5.1, U1.36 (3V3), U2.1 (3V3), U3.2 (VO)
+5V: C1.1, U1.40 (VBUS), U3.3 (VI)
/A0: J4.4, U1.31 (GPIO26_ADC0)
/A1: J4.3, U1.32 (GPIO27_ADC1)
/A2: J4.2, U1.34 (GPIO28_ADC2)
/AGND: J4.1, U1.33 (AGND)
/CS: U1.7 (GPIO5), U2.10 (IO10)
/D0: J1.1, U1.15 (GPIO11)
/D1: J1.2, U1.16 (GPIO12)
/D2: J1.3, U1.17 (GPIO13)
/D3: J1.4, U1.19 (GPIO14)
/D4: J1.8, U1.20 (GPIO15)
/D5: J1.7, U1.21 (GPIO16)
/D6: J1.6, U1.22 (GPIO17)
/D7: J1.5, U1.24 (GPIO18)
/D8: J2.4, U1.25 (GPIO19)
/D9: J2.3, U1.26 (GPIO20)
/D10: J2.1, U1.27 (GPIO21)
/D11: J2.2, U1.29 (GPIO22)
/EN: C3.1, ESP RST.1, R5.2, U2.2 (EN)
/IO2: R3.2, U1.6 (GPIO4), U2.16 (IO2)
/IO8: R4.2, U2.7 (IO8)
/IO9: ESP BOOT.1, U2.8 (IO9)
/MOSI: U1.5 (GPIO3), U2.6 (IO7)
/READY: U1.9 (GPIO6), U2.3 (IO4)
/RST: Pico RST.1, U1.30 (RUN)
/RX: J5.3, J6.3, U1.12 (GPIO9)
/RXD: J5.6, U2.12 (IO21/TXD)
/S0: J6.2, U1.10 (GPIO7)
/S1: J6.4, U1.14 (GPIO10)
/SCK: U1.4 (GPIO2), U2.5 (IO6)
/SCL: J7.4, U1.2 (GPIO1)
/SDA: J7.3, U1.1 (GPIO0)
/TX: J5.4, J6.1, U1.11 (GPIO8)
/TXD: J5.5, U2.11 (IO20/RXD)
GND: C1.2, C2.2, C3.2, C4.1, C5.2, ESP BOOT.2, ESP RST.2, J3.1, J3.2, J3.3, J3.4, J7.1, Pico RST.2, U1.3 (GND), U1.13 (GND), U1.18 (GND), U1.23 (GND), U1.28 (GND), U1.38 (GND), U1.42 (GND), U2.9 (GND), U2.19 (GND), U3.1 (GND)

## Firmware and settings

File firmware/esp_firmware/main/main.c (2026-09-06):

#include <errno.h>
#include <inttypes.h>
#include <stdbool.h>
#include <stdint.h>
#include <stdio.h>
#include <string.h>

#include "driver/gpio.h"
#include "driver/spi_slave.h"
#include "esp_check.h"
#include "esp_event.h"
#include "esp_heap_caps.h"
#include "esp_log.h"
#include "esp_netif.h"
#include "esp_timer.h"
#include "esp_wifi.h"
#include "freertos/FreeRTOS.h"
#include "freertos/event_groups.h"
#include "freertos/queue.h"
#include "freertos/task.h"
#include "lwip/inet.h"
#include "lwip/sockets.h"
#include "mdns_service.h"
#include "nvs_flash.h"

#include "wifi_provisioning.h"

#define FRAME_LEN 512
#define HEADER_LEN 12
#define MAX_PAYLOAD_LEN (FRAME_LEN - HEADER_LEN)
#define FRAME_MAGIC 0xa5
#define FRAME_TYPE_POLL 0x00
#define FRAME_TYPE_DATA 0x02
#define FRAME_TYPE_SCPI 0x03
#define SLOT_COUNT 12
#define SPI_QUEUED_TRANSFERS 4
#define UDP_BATCH_FRAMES 2
#define UDP_PACKET_LEN (FRAME_LEN * UDP_BATCH_FRAMES)
#define SCPI_QUEUE_DEPTH 8
#define WIFI_CONNECTED_BIT BIT0
#define WIFI_FAIL_BIT BIT1

static char const *const TAG = "esp_spi_udp_bridge";
static char const UDP_REGISTER_REQUEST[] = "LIBRELAB_UDP_REGISTER";

typedef struct {
    uint8_t *tx;
    uint8_t *rx;
    spi_slave_transaction_t trans;
    uint32_t sequence;
} bridge_slot_t;

typedef struct {
    uint16_t len;
    uint8_t data[MAX_PAYLOAD_LEN];
} bridge_message_t;

static EventGroupHandle_t wifi_event_group;
static QueueHandle_t free_queue;
static QueueHandle_t full_queue;
static QueueHandle_t scpi_rx_queue;
static QueueHandle_t scpi_tx_queue;
static bridge_slot_t slots[SLOT_COUNT];
static int sta_retry_count;

static uint8_t checksum8(uint8_t const *data, size_t len)
{
    uint8_t sum = 0;
    for (size_t i = 0; i < len; ++i) {
        sum = (uint8_t)(sum + data[i]);
    }
    return sum;
}

static uint16_t get_u16_le(uint8_t const *data)
{
    return (uint16_t)data[0] | ((uint16_t)data[1] << 8);
}

static uint32_t get_u32_le(uint8_t const *data)
{
    return (uint32_t)data[0] |
           ((uint32_t)data[1] << 8) |
           ((uint32_t)data[2] << 16) |
           ((uint32_t)data[3] << 24);
}

typedef struct {
    uint32_t magic;
    uint32_t type;
    uint32_t length;
    uint32_t checksum;
} frame_error_stats_t;

static void put_u16_le(uint8_t *data, uint16_t value)
{
    data[0] = (uint8_t)value;
    data[1] = (uint8_t)(value >> 8);
}

static void put_u32_le(uint8_t *data, uint32_t value)
{
    data[0] = (uint8_t)value;
    data[1] = (uint8_t)(value >> 8);
    data[2] = (uint8_t)(value >> 16);
    data[3] = (uint8_t)(value >> 24);
}

static void prepare_frame(
    uint8_t *frame,
    uint8_t frame_type,
    uint32_t seq,
    uint8_t const *payload,
    uint16_t payload_len
)
{
    memset(frame, 0, FRAME_LEN);
    frame[0] = FRAME_MAGIC;
    frame[1] = frame_type;
    put_u32_le(&frame[2], seq);
    put_u16_le(&frame[6], payload_len);
    frame[8] = checksum8(frame, 8);
    if (payload && payload_len > 0) {
        memcpy(&frame[HEADER_LEN], payload, payload_len);
    }
}

static void prepare_poll_frame(uint8_t *frame, uint32_t seq)
{
    prepare_frame(frame, FRAME_TYPE_POLL, seq, NULL, 0);
}

static uint32_t validate_rx_frame(
    uint8_t const *frame,
    uint8_t *type_out,
    uint32_t *seq_out,
    uint16_t *len_out,
    frame_error_stats_t *stats
)
{
    uint32_t errors = 0;
    if (frame[0] != FRAME_MAGIC) {
        ++errors;
        if (stats) {
            ++stats->magic;
        }
    }
    if (frame[1] != FRAME_TYPE_DATA && frame[1] != FRAME_TYPE_SCPI &&
        frame[1] != FRAME_TYPE_POLL) {
        ++errors;
        if (stats) {
            ++stats->type;
        }
    }
    uint16_t len = get_u16_le(&frame[6]);
    if (len > MAX_PAYLOAD_LEN) {
        ++errors;
        if (stats) {
            ++stats->length;
        }
        len = 0;
    }
    if (frame[8] != checksum8(frame, 8)) {
        ++errors;
        if (stats) {
            ++stats->checksum;
        }
    }

    *type_out = frame[1];
    *seq_out = get_u32_le(&frame[2]);
    *len_out = len;
    return errors;
}

static void set_ready(bool ready)
{
    gpio_set_level(CONFIG_ESP_BRIDGE_PIN_READY, ready ? 1 : 0);
}

static void wifi_event_handler(void *arg, esp_event_base_t event_base, int32_t event_id, void *event_data)
{
    (void)arg;
    if (event_base == WIFI_EVENT && event_id == WIFI_EVENT_STA_START) {
        esp_wifi_connect();
    } else if (event_base == WIFI_EVENT && event_id == WIFI_EVENT_STA_DISCONNECTED) {
        if (sta_retry_count < 10) {
            ++sta_retry_count;
            ESP_LOGI(TAG, "retrying station connection");
            esp_wifi_connect();
        } else {
            xEventGroupSetBits(wifi_event_group, WIFI_FAIL_BIT);
        }
    } else if (event_base == IP_EVENT && event_id == IP_EVENT_STA_GOT_IP) {
        ip_event_got_ip_t *event = (ip_event_got_ip_t *)event_data;
        ESP_LOGI(TAG, "station IP: " IPSTR, IP2STR(&event->ip_info.ip));
        sta_retry_count = 0;
        xEventGroupSetBits(wifi_event_group, WIFI_CONNECTED_BIT);
    }
}

static bool start_station(wifi_provisioning_credentials_t const *credentials)
{
    wifi_config_t sta_config = {0};
    strlcpy((char *)sta_config.sta.ssid, credentials->ssid, sizeof(sta_config.sta.ssid));
    strlcpy((char *)sta_config.sta.password, credentials->password, sizeof(sta_config.sta.password));
    sta_config.sta.threshold.authmode = WIFI_AUTH_WPA2_PSK;

    xEventGroupClearBits(wifi_event_group, WIFI_CONNECTED_BIT | WIFI_FAIL_BIT);
    sta_retry_count = 0;
    if (esp_wifi_set_mode(WIFI_MODE_STA) != ESP_OK ||
        esp_wifi_set_config(WIFI_IF_STA, &sta_config) != ESP_OK ||
        esp_wifi_start() != ESP_OK) {
        (void)esp_wifi_stop();
        return false;
    }
    if (esp_wifi_set_ps(WIFI_PS_NONE) != ESP_OK) {
        esp_wifi_stop();
        return false;
    }

    EventBits_t bits = xEventGroupWaitBits(
        wifi_event_group,
        WIFI_CONNECTED_BIT | WIFI_FAIL_BIT,
        pdFALSE,
        pdFALSE,
        pdMS_TO_TICKS(15000)
    );
    if (bits & WIFI_CONNECTED_BIT) {
        ESP_LOGI(TAG, "station connected");
        if (!mdns_service_start(CONFIG_ESP_BRIDGE_LOCAL_PORT)) {
            ESP_LOGW(TAG, "mDNS discovery unavailable");
        }
        return true;
    } else {
        ESP_LOGW(TAG, "station connection not established yet");
        esp_wifi_stop();
        return false;
    }
}

static bool start_wifi(void)
{
    ESP_ERROR_CHECK(esp_netif_init());
    ESP_ERROR_CHECK(esp_event_loop_create_default());
    wifi_event_group = xEventGroupCreate();
    if (!wifi_event_group) {
        return false;
    }

    esp_netif_create_default_wifi_ap();
    esp_netif_create_default_wifi_sta();

    wifi_init_config_t init_config = WIFI_INIT_CONFIG_DEFAULT();
    if (esp_wifi_init(&init_config) != ESP_OK ||
        esp_event_handler_register(WIFI_EVENT, ESP_EVENT_ANY_ID, &wifi_event_handler, NULL) != ESP_OK ||
        esp_event_handler_register(IP_EVENT, IP_EVENT_STA_GOT_IP, &wifi_event_handler, NULL) != ESP_OK) {
        return false;
    }

    wifi_provisioning_credentials_t credentials = {0};
    if (!wifi_provisioning_load_credentials(&credentials)) {
        ESP_LOGI(TAG, "no saved Wi-Fi credentials; starting setup network");
        if (!wifi_provisioning_run(&credentials)) {
            return false;
        }
    }

    if (start_station(&credentials)) {
        return true;
    }

    ESP_LOGW(TAG, "saved station configuration failed; starting setup network");
    if (!wifi_provisioning_run(&credentials)) {
        return false;
    }
    return start_station(&credentials);
}

static void init_spi(void)
{
    gpio_config_t ready_config = {
        .pin_bit_mask = 1ULL << CONFIG_ESP_BRIDGE_PIN_READY,
        .mode = GPIO_MODE_OUTPUT,
        .pull_up_en = GPIO_PULLUP_DISABLE,
        .pull_down_en = GPIO_PULLDOWN_DISABLE,
        .intr_type = GPIO_INTR_DISABLE,
    };
    ESP_ERROR_CHECK(gpio_config(&ready_config));
    set_ready(false);

    spi_bus_config_t buscfg = {
        .mosi_io_num = CONFIG_ESP_BRIDGE_PIN_MOSI,
        .miso_io_num = CONFIG_ESP_BRIDGE_PIN_MISO,
        .sclk_io_num = CONFIG_ESP_BRIDGE_PIN_SCLK,
        .quadwp_io_num = -1,
        .quadhd_io_num = -1,
        .max_transfer_sz = FRAME_LEN,
    };

    spi_slave_interface_config_t slvcfg = {
        .mode = 0,
        .spics_io_num = CONFIG_ESP_BRIDGE_PIN_CS,
        .queue_size = SPI_QUEUED_TRANSFERS,
        .flags = 0,
    };

    ESP_ERROR_CHECK(spi_slave_initialize(SPI2_HOST, &buscfg, &slvcfg, SPI_DMA_CH_AUTO));
}

static void init_slots(void)
{
    free_queue = xQueueCreate(SLOT_COUNT, sizeof(uint32_t));
    full_queue = xQueueCreate(SLOT_COUNT, sizeof(uint32_t));
    scpi_rx_queue = xQueueCreate(SCPI_QUEUE_DEPTH, sizeof(bridge_message_t));
    scpi_tx_queue = xQueueCreate(SCPI_QUEUE_DEPTH, sizeof(bridge_message_t));
    ESP_ERROR_CHECK((free_queue && full_queue && scpi_rx_queue && scpi_tx_queue) ?
        ESP_OK : ESP_ERR_NO_MEM);

    for (uint32_t i = 0; i < SLOT_COUNT; ++i) {
        slots[i].tx = heap_caps_malloc(FRAME_LEN, MALLOC_CAP_DMA);
        slots[i].rx = heap_caps_malloc(FRAME_LEN, MALLOC_CAP_DMA);
        ESP_ERROR_CHECK((slots[i].tx && slots[i].rx) ? ESP_OK : ESP_ERR_NO_MEM);
        memset(&slots[i].trans, 0, sizeof(slots[i].trans));
        slots[i].trans.length = FRAME_LEN * 8;
        slots[i].trans.tx_buffer = slots[i].tx;
        slots[i].trans.rx_buffer = slots[i].rx;
        slots[i].trans.user = (void *)(uintptr_t)i;
        prepare_poll_frame(slots[i].tx, i);
        memset(slots[i].rx, 0, FRAME_LEN);
        slots[i].sequence = 0;
    }
}

static void queue_slot(uint32_t slot_index, uint32_t poll_seq)
{
    bridge_message_t scpi_msg;
    if (xQueueReceive(scpi_rx_queue, &scpi_msg, 0) == pdTRUE) {
        prepare_frame(
            slots[slot_index].tx,
            FRAME_TYPE_SCPI,
            poll_seq,
            scpi_msg.data,
            scpi_msg.len
        );
    } else {
        prepare_poll_frame(slots[slot_index].tx, poll_seq);
    }
    memset(slots[slot_index].rx, 0, FRAME_LEN);
    ESP_ERROR_CHECK(spi_slave_queue_trans(SPI2_HOST, &slots[slot_index].trans, pdMS_TO_TICKS(1000)));
}

static void refill_spi_queue(uint32_t *queued, uint32_t *poll_seq)
{
    while (*queued < SPI_QUEUED_TRANSFERS) {
        uint32_t free_slot = 0;
        TickType_t wait = (*queued == 0) ? portMAX_DELAY : 0;
        if (xQueueReceive(free_queue, &free_slot, wait) != pdTRUE) {
            break;
        }
        queue_slot(free_slot, (*poll_seq)++);
        ++(*queued);
    }
    set_ready(*queued > 0);
}

static bool udp_endpoint_changed(struct sockaddr_in const *a, struct sockaddr_in const *b)
{
    return a->sin_addr.s_addr != b->sin_addr.s_addr || a->sin_port != b->sin_port;
}

static void log_udp_endpoint(char const *label, struct sockaddr_in const *addr)
{
    char host_ip[16];
    inet_ntoa_r(addr->sin_addr, host_ip, sizeof(host_ip));
    ESP_LOGI(TAG, "%s %s:%u", label, host_ip, ntohs(addr->sin_port));
}

static int send_udp_with_retry(
    int sock,
    uint8_t const *packet,
    size_t packet_len,
    struct sockaddr_in const *dest_addr,
    uint32_t *retry_count,
    int *last_errno
)
{
    for (int attempt = 0; attempt < 4; ++attempt) {
        int sent = sendto(sock, packet, packet_len, 0, (struct sockaddr *)dest_addr, sizeof(*dest_addr));
        if (sent == (int)packet_len) {
            return sent;
        }

        *last_errno = errno;
        if (errno != ENOMEM && errno != EAGAIN && errno != ENOBUFS) {
            return sent;
        }

        ++(*retry_count);
        if (attempt < 2) {
            taskYIELD();
        } else {
            vTaskDelay(1);
        }
    }

    return -1;
}

static bool line_is_query(uint8_t const *line, size_t len)
{
    for (size_t i = 0; i < len; ++i) {
        if (line[i] == '?') {
            return true;
        }
    }
    return false;
}

static bool queue_scpi_line(uint8_t const *line, size_t len)
{
    if (!line || len == 0) {
        return false;
    }

    bridge_message_t scpi_msg = {
        .len = (uint16_t)len,
    };
    if (scpi_msg.len > MAX_PAYLOAD_LEN) {
        scpi_msg.len = MAX_PAYLOAD_LEN;
    }
    memcpy(scpi_msg.data, line, scpi_msg.len);
    if (scpi_msg.len < MAX_PAYLOAD_LEN &&
        scpi_msg.data[scpi_msg.len - 1] != '\n') {
        scpi_msg.data[scpi_msg.len++] = '\n';
    }
    return xQueueSend(scpi_rx_queue, &scpi_msg, pdMS_TO_TICKS(250)) == pdTRUE;
}

static void flush_scpi_tx_queue(void)
{
    bridge_message_t discarded;
    while (xQueueReceive(scpi_tx_queue, &discarded, 0) == pdTRUE) {
    }
}

static void spi_task(void *arg)
{
    (void)arg;
    uint32_t poll_seq = 0;
    uint32_t queued = 0;
    uint32_t spi_frames = 0;
    uint32_t spi_errors = 0;
    uint32_t queue_drops = 0;
    uint32_t scpi_frames = 0;
    uint32_t last_seq = 0;
    frame_error_stats_t error_stats = {0};
    int64_t report_start = esp_timer_get_time();

    for (uint32_t i = 0; i < SPI_QUEUED_TRANSFERS; ++i) {
        queue_slot(i, poll_seq++);
        ++queued;
    }
    for (uint32_t i = SPI_QUEUED_TRANSFERS; i < SLOT_COUNT; ++i) {
        xQueueSend(free_queue, &i, 0);
    }
    set_ready(true);

    while (true) {
        refill_spi_queue(&queued, &poll_seq);

        spi_slave_transaction_t *completed = NULL;
        esp_err_t err = spi_slave_get_trans_result(SPI2_HOST, &completed, pdMS_TO_TICKS(1000));
        if (err != ESP_OK) {
            ++spi_errors;
            continue;
        }

        if (queued > 0) {
            --queued;
        }

        uint32_t slot_index = (uint32_t)(uintptr_t)completed->user;
        uint8_t frame_type = FRAME_TYPE_POLL;
        uint32_t seq = 0;
        uint16_t frame_len = 0;
        uint32_t frame_errors = validate_rx_frame(
            slots[slot_index].rx,
            &frame_type,
            &seq,
            &frame_len,
            &error_stats
        );
        spi_errors += frame_errors;
        last_seq = seq;
        ++spi_frames;

        if (frame_errors == 0 && frame_type == FRAME_TYPE_DATA) {
            slots[slot_index].sequence = seq;
            if (xQueueSend(full_queue, &slot_index, 0) != pdTRUE) {
                ++queue_drops;
                xQueueSend(free_queue, &slot_index, 0);
            }
        } else if (frame_errors == 0 && frame_type == FRAME_TYPE_SCPI) {
            bridge_message_t scpi_msg = {
                .len = frame_len,
            };
            if (frame_len > 0) {
                memcpy(scpi_msg.data, &slots[slot_index].rx[HEADER_LEN], frame_len);
            }
            if (xQueueSend(scpi_tx_queue, &scpi_msg, 0) != pdTRUE) {
                ++queue_drops;
            } else {
                ++scpi_frames;
            }
            xQueueSend(free_queue, &slot_index, 0);
        } else {
            xQueueSend(free_queue, &slot_index, 0);
        }

        refill_spi_queue(&queued, &poll_seq);

        int64_t now = esp_timer_get_time();
        if (now - report_start >= (int64_t)CONFIG_ESP_BRIDGE_REPORT_INTERVAL_MS * 1000) {
            printf("spi_frames=%" PRIu32 ",queued=%" PRIu32 ",spi_errors=%" PRIu32 ",magic=%" PRIu32 ",type=%" PRIu32 ",len=%" PRIu32 ",chk=%" PRIu32 ",queue_drops=%" PRIu32 ",scpi_frames=%" PRIu32 ",last_seq=%" PRIu32 "\n",
                   spi_frames,
                   queued,
                   spi_errors,
                   error_stats.magic,
                   error_stats.type,
                   error_stats.length,
                   error_stats.checksum,
                   queue_drops,
                   scpi_frames,
                   last_seq);
            spi_frames = 0;
            spi_errors = 0;
            queue_drops = 0;
            scpi_frames = 0;
            error_stats = (frame_error_stats_t){0};
            report_start = now;
        }
    }
}

static void udp_task(void *arg)
{
    (void)arg;
    if (!start_wifi()) {
        ESP_LOGE(TAG, "Wi-Fi setup failed");
        vTaskDelete(NULL);
    }

    int sock = socket(AF_INET, SOCK_DGRAM, IPPROTO_UDP);
    if (sock < 0) {
        ESP_LOGE(TAG, "socket failed errno=%d", errno);
        vTaskDelete(NULL);
    }

    int broadcast_enable = 1;
    setsockopt(sock, SOL_SOCKET, SO_BROADCAST, &broadcast_enable, sizeof(broadcast_enable));
    int send_buffer_size = 16 * 1024;
    setsockopt(sock, SOL_SOCKET, SO_SNDBUF, &send_buffer_size, sizeof(send_buffer_size));

    struct sockaddr_in local_addr = {
        .sin_family = AF_INET,
        .sin_port = htons(CONFIG_ESP_BRIDGE_LOCAL_PORT),
        .sin_addr.s_addr = htonl(INADDR_ANY),
    };
    if (bind(sock, (struct sockaddr *)&local_addr, sizeof(local_addr)) < 0) {
        ESP_LOGW(TAG, "bind failed errno=%d", errno);
    }

    struct sockaddr_in wave_dest_addr = {
        .sin_family = AF_INET,
        .sin_port = htons(CONFIG_ESP_BRIDGE_DEST_PORT),
    };
    inet_aton(CONFIG_ESP_BRIDGE_DEST_IP, &wave_dest_addr.sin_addr);

    bool using_wave_unicast = false;
    uint32_t udp_packets = 0;
    uint32_t udp_frames = 0;
    uint32_t udp_errors = 0;
    uint32_t udp_retries = 0;
    uint32_t last_seq = 0;
    uint64_t bytes_sent = 0;
    int last_errno = 0;
    uint8_t *udp_packet = heap_caps_malloc(UDP_PACKET_LEN, MALLOC_CAP_8BIT);
    ESP_ERROR_CHECK(udp_packet ? ESP_OK : ESP_ERR_NO_MEM);
    int64_t report_start = esp_timer_get_time();

    ESP_LOGI(TAG, "UDP initial destination %s:%d", CONFIG_ESP_BRIDGE_DEST_IP, CONFIG_ESP_BRIDGE_DEST_PORT);

    while (true) {
        uint8_t control_buffer[MAX_PAYLOAD_LEN];
        struct sockaddr_in control_addr = {0};
        socklen_t control_addr_len = sizeof(control_addr);
        int control_len = recvfrom(
            sock,
            control_buffer,
            sizeof(control_buffer),
            MSG_DONTWAIT,
            (struct sockaddr *)&control_addr,
            &control_addr_len
        );
        if (control_len > 0) {
            if (control_len == sizeof(UDP_REGISTER_REQUEST) - 1 &&
                memcmp(control_buffer, UDP_REGISTER_REQUEST,
                       sizeof(UDP_REGISTER_REQUEST) - 1) == 0) {
                bool changed = !using_wave_unicast ||
                               udp_endpoint_changed(&wave_dest_addr, &control_addr);
                wave_dest_addr = control_addr;
                using_wave_unicast = true;
                if (changed) {
                    log_udp_endpoint("registered waveform host", &wave_dest_addr);
                }
            }
        }

        uint32_t batch_slots[UDP_BATCH_FRAMES] = {0};
        uint32_t batch_count = 0;
        if (xQueueReceive(full_queue, &batch_slots[batch_count], pdMS_TO_TICKS(20)) != pdTRUE) {
            continue;
        }
        ++batch_count;

        while (batch_count < UDP_BATCH_FRAMES) {
            if (xQueueReceive(full_queue, &batch_slots[batch_count], pdMS_TO_TICKS(1)) != pdTRUE) {
                break;
            }
            ++batch_count;
        }

        for (uint32_t i = 0; i < batch_count; ++i) {
            memcpy(&udp_packet[i * FRAME_LEN], slots[batch_slots[i]].rx, FRAME_LEN);
            last_seq = slots[batch_slots[i]].sequence;
        }

        int sent = send_udp_with_retry(
            sock,
            udp_packet,
            batch_count * FRAME_LEN,
            &wave_dest_addr,
            &udp_retries,
            &last_errno
        );
        if (sent == (int)(batch_count * FRAME_LEN)) {
            ++udp_packets;
            udp_frames += batch_count;
            bytes_sent += (uint64_t)sent;
        } else {
            ++udp_errors;
            last_errno = errno;
        }

        for (uint32_t i = 0; i < batch_count; ++i) {
            xQueueSend(free_queue, &batch_slots[i], portMAX_DELAY);
        }

        int64_t now = esp_timer_get_time();
        if (now - report_start >= (int64_t)CONFIG_ESP_BRIDGE_REPORT_INTERVAL_MS * 1000) {
            double seconds = (now - report_start) / 1000000.0;
            double kbyte_s = seconds > 0.0 ? (bytes_sent / seconds / 1000.0) : 0.0;
            double mbit_s = seconds > 0.0 ? (bytes_sent * 8.0 / seconds / 1000000.0) : 0.0;
            printf("udp_packets=%" PRIu32 ",udp_frames=%" PRIu32 ",bytes=%" PRIu64 ",kbyte_s=%.3f,mbit_s=%.3f,udp_errors=%" PRIu32 ",udp_retries=%" PRIu32 ",last_errno=%d,mode=%s,last_seq=%" PRIu32 "\n",
                   udp_packets,
                   udp_frames,
                   bytes_sent,
                   kbyte_s,
                   mbit_s,
                   udp_errors,
                   udp_retries,
                   last_errno,
                   using_wave_unicast ? "unicast" : "broadcast",
                   last_seq);
            udp_packets = 0;
            udp_frames = 0;
            udp_errors = 0;
            udp_retries = 0;
            bytes_sent = 0;
            last_errno = 0;
            report_start = now;
        }
    }
}
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
void app_main(void)
{
    esp_err_t ret = nvs_flash_init();
    if (ret == ESP_ERR_NVS_NO_FREE_PAGES || ret == ESP_ERR_NVS_NEW_VERSION_FOUND) {
        ESP_ERROR_CHECK(nvs_flash_erase());
        ret = nvs_flash_init();
    }
    ESP_ERROR_CHECK(ret);

    ESP_LOGI(TAG, "ESP SPI -> UDP bridge");
    ESP_LOGI(TAG, "SCLK=%d MOSI_IN=%d MISO_OUT=%d CS=%d READY_OUT=%d",
             CONFIG_ESP_BRIDGE_PIN_SCLK,
             CONFIG_ESP_BRIDGE_PIN_MOSI,
             CONFIG_ESP_BRIDGE_PIN_MISO,
             CONFIG_ESP_BRIDGE_PIN_CS,
             CONFIG_ESP_BRIDGE_PIN_READY);

    init_spi();
    init_slots();

    xTaskCreate(spi_task, "spi_task", 4096, NULL, 6, NULL);
    xTaskCreate(udp_task, "udp_task", 4096, NULL, 5, NULL);
    xTaskCreate(tcp_scpi_task, "tcp_scpi_task", 4096, NULL, 4, NULL);
}

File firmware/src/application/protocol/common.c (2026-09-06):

/**
 * @file common.c
 * @brief SCPI common infrastructure
 *
 * This module implements the common SCPI protocol infrastructure including
 * USB communication, SCPI context management, and IEEE 488.2 commands.
 */

#include "application/protocol.h"

#include <stdbool.h>
#include <stdint.h>
#include <stdio.h>
#include <string.h>

#include "scpi/error.h"
#include "scpi/scpi.h"

#include "application/communication_commands.h"
#include "application/dso_commands.h"
#include "application/logic_analyser_commands.h"
#include "application/mixed_signal_commands.h"
#include "application/pattern_generator_commands.h"
#include "application/protocol/bus/i2c.h"
#include "application/protocol/bus/spi.h"
#include "application/protocol/bus/uart.h"
#include "platform/platform.h"
#include "platform/status_led.h"
#include "platform/usb_cdc.h"
#include "system/transport.h"
#include "util/logging.h"

// Buffer sizes for USB communication (internal to this module)
enum {
    USB_RX_CHUNK_SIZE = 64,
    WIFI_RX_CHUNK_SIZE = 256,
    SCPI_INPUT_BUFFER_SIZE = 1024,
    SCPI_ERROR_QUEUE_SIZE = 16
};

// Forward declarations of logic analyser functions needed by common
extern scpi_result_t scpi_cmd_configure_logic_analyser_pinbase(scpi_t *context);
extern scpi_result_t scpi_cmd_configure_logic_analyser_pinbase_q(scpi_t *context);
extern scpi_result_t scpi_cmd_configure_logic_analyser_pincount(scpi_t *context);
extern scpi_result_t scpi_cmd_configure_logic_analyser_pincount_q(scpi_t *context);
extern scpi_result_t scpi_cmd_configure_logic_analyser_samples(scpi_t *context);
extern scpi_result_t scpi_cmd_configure_logic_analyser_samples_q(scpi_t *context);
extern scpi_result_t scpi_cmd_configure_logic_analyser_divider(scpi_t *context);
extern scpi_result_t scpi_cmd_configure_logic_analyser_divider_q(scpi_t *context);
extern scpi_result_t scpi_cmd_configure_logic_analyser_rate_q(scpi_t *context);
extern scpi_result_t scpi_cmd_configure_logic_analyser_trigger_pin(scpi_t *context);
extern scpi_result_t scpi_cmd_configure_logic_analyser_trigger_pin_q(scpi_t *context);
extern scpi_result_t scpi_cmd_configure_logic_analyser_trigger_level(scpi_t *context);
extern scpi_result_t scpi_cmd_configure_logic_analyser_trigger_level_q(scpi_t *context);
extern scpi_result_t scpi_cmd_configure_logic_analyser_trigger_mode(scpi_t *context);
extern scpi_result_t scpi_cmd_configure_logic_analyser_trigger_mode_q(scpi_t *context);
extern scpi_result_t scpi_cmd_initiate_logic_analyser(scpi_t *context);
extern scpi_result_t scpi_cmd_fetch_logic_analyser_data_q(scpi_t *context);
extern scpi_result_t scpi_cmd_read_logic_analyser_q(scpi_t *context);
extern scpi_result_t scpi_cmd_status_logic_analyser_q(scpi_t *context);
extern scpi_result_t scpi_cmd_metadata_logic_analyser_q(scpi_t *context);
extern scpi_result_t scpi_cmd_stream_logic_analyser_start(scpi_t *context);
extern scpi_result_t scpi_cmd_stream_logic_analyser_stop(scpi_t *context);
extern scpi_result_t scpi_cmd_stream_logic_analyser_status_q(scpi_t *context);

// Forward declarations of oscilloscope functions needed by common
extern scpi_result_t scpi_cmd_configure_dso_channel(scpi_t *context);
extern scpi_result_t scpi_cmd_configure_dso_channel_q(scpi_t *context);
extern scpi_result_t scpi_cmd_configure_dso_gpio_q(scpi_t *context);
extern scpi_result_t scpi_cmd_configure_dso_samples(scpi_t *context);
extern scpi_result_t scpi_cmd_configure_dso_samples_q(scpi_t *context);
extern scpi_result_t scpi_cmd_configure_dso_rate(scpi_t *context);
extern scpi_result_t scpi_cmd_configure_dso_rate_q(scpi_t *context);
extern scpi_result_t scpi_cmd_configure_dso_trigger_level(scpi_t *context);
extern scpi_result_t scpi_cmd_configure_dso_trigger_level_q(scpi_t *context);
extern scpi_result_t scpi_cmd_configure_dso_trigger_mode(scpi_t *context);
extern scpi_result_t scpi_cmd_configure_dso_trigger_mode_q(scpi_t *context);
extern scpi_result_t scpi_cmd_configure_dso_trigger_slope(scpi_t *context);
extern scpi_result_t scpi_cmd_configure_dso_trigger_slope_q(scpi_t *context);
extern scpi_result_t scpi_cmd_initiate_dso(scpi_t *context);
extern scpi_result_t scpi_cmd_fetch_dso_data_q(scpi_t *context);
extern scpi_result_t scpi_cmd_read_dso_q(scpi_t *context);
extern scpi_result_t scpi_cmd_status_dso_q(scpi_t *context);
extern scpi_result_t scpi_cmd_stream_dso_start(scpi_t *context);
extern scpi_result_t scpi_cmd_stream_dso_stop(scpi_t *context);
extern scpi_result_t scpi_cmd_stream_dso_status_q(scpi_t *context);

// Forward declarations of mixed-signal functions needed by common
extern scpi_result_t scpi_cmd_configure_mso_digital_pinbase(scpi_t *context);
extern scpi_result_t scpi_cmd_configure_mso_digital_pinbase_q(scpi_t *context);
extern scpi_result_t scpi_cmd_configure_mso_digital_pincount(scpi_t *context);
extern scpi_result_t scpi_cmd_configure_mso_digital_pincount_q(scpi_t *context);
extern scpi_result_t scpi_cmd_configure_mso_analog_channel(scpi_t *context);
extern scpi_result_t scpi_cmd_configure_mso_analog_channel_q(scpi_t *context);
extern scpi_result_t scpi_cmd_configure_mso_samples(scpi_t *context);
extern scpi_result_t scpi_cmd_configure_mso_samples_q(scpi_t *context);
extern scpi_result_t scpi_cmd_configure_mso_rate(scpi_t *context);
extern scpi_result_t scpi_cmd_configure_mso_rate_q(scpi_t *context);
extern scpi_result_t scpi_cmd_configure_mso_trigger_pin(scpi_t *context);
extern scpi_result_t scpi_cmd_configure_mso_trigger_pin_q(scpi_t *context);
extern scpi_result_t scpi_cmd_configure_mso_trigger_level(scpi_t *context);
extern scpi_result_t scpi_cmd_configure_mso_trigger_level_q(scpi_t *context);
extern scpi_result_t scpi_cmd_configure_mso_trigger_mode(scpi_t *context);
extern scpi_result_t scpi_cmd_configure_mso_trigger_mode_q(scpi_t *context);
extern scpi_result_t scpi_cmd_initiate_mso(scpi_t *context);
extern scpi_result_t scpi_cmd_fetch_mso_digital_q(scpi_t *context);
extern scpi_result_t scpi_cmd_fetch_mso_analog_q(scpi_t *context);
extern scpi_result_t scpi_cmd_read_mso_digital_q(scpi_t *context);
extern scpi_result_t scpi_cmd_read_mso_analog_q(scpi_t *context);
extern scpi_result_t scpi_cmd_status_mso_q(scpi_t *context);
extern scpi_result_t scpi_cmd_metadata_mso_q(scpi_t *context);
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
